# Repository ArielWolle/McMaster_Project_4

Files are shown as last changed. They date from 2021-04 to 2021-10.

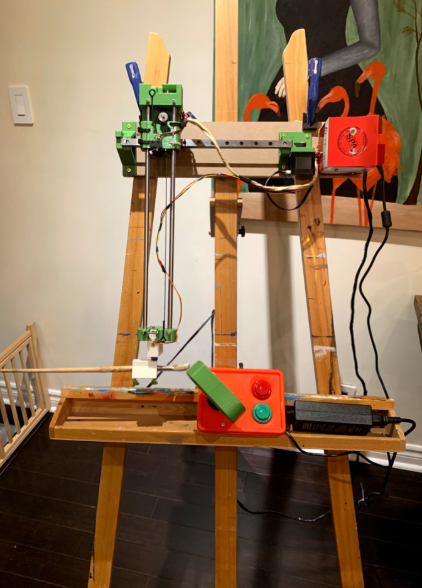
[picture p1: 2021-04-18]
Images/Plotter_on_easel.png

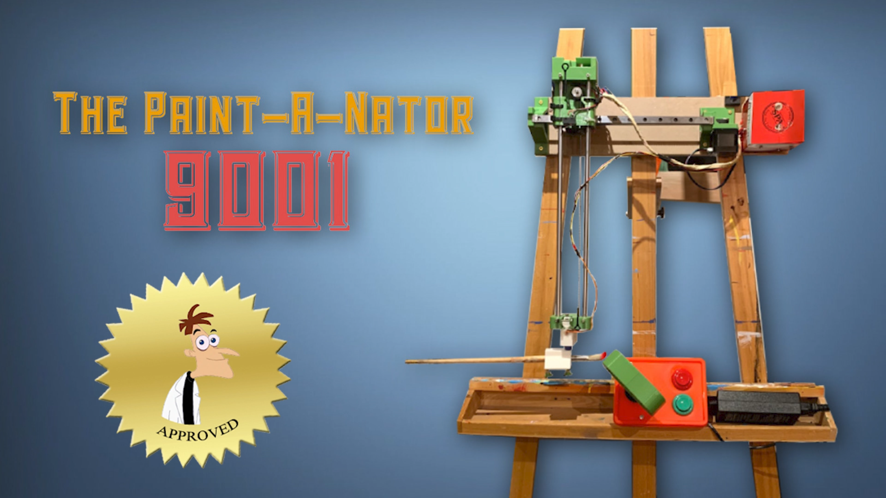
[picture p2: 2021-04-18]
Images/Plotter_title_page.png

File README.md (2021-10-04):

# McMaster_Project_4
ENG1P13 Project 4

This is a custom pen plotter based of of DIY-Machines design on thingiverse. This design was a end of year engineering project that I completed in a group of 4 where the challenge was to help a person with disiblities in their life. We chose to help the person be able to paint again. This design uses a custsom ergonomic joystick and 2 arcade style butons as inputs. 

https://www.youtube.com/watch?v=c9EO0ap5n0Y

Plotter_on_easel

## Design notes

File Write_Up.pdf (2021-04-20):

## Project Four – Power in Community

## The Paint-A-Nator 9001

ENGINEER 1P13 – Integrated Cornerstone Design Projects

Tutorial 03 & 15

Mon-46

Milica Nenadovic (nenadovm)

W. Tisuka Perera (pererw2)

Ariel Wolle (wollea)

Yara Sharafeldin (sharafey)

Submitted: April 14th, 2021.

1P13 DP-4 Final Report | Tutorial 03 & 15 | Mon-46

Table of Contents

Academic Integrity Statement

The student is responsible for performing the required work in an honest manner, without plagiarism and cheating. Submitting this

work with my name and student number is a statement and understanding that this work is my own and adheres to the Academic

Integrity Policy of McMaster University.

Milica Nenadovic | 400312492

X

The student is responsible for performing the required work in an honest manner, without plagiarism and cheating. Submitting this

work with my name and student number is a statement and understanding that this work is my own and adheres to the Academic

Integrity Policy of McMaster University.

W. Tisuka Perera | 400318373

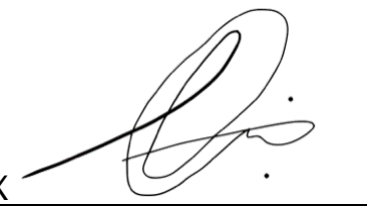
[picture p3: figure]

X

The student is responsible for performing the required work in an honest manner, without plagiarism and cheating. Submitting this

work with my name and student number is a statement and understanding that this work is my own and adheres to the Academic

Integrity Policy of McMaster University.

Yara Sharafeldin | 400294445

X Yara Sharafeldin

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

Integrity Policy of McMaster University.

Ariel Wolle | 400307171

X

Executive Summary

As a team we were tasked with analyzing and designing a product that would prove helpful to our client

and help ease her life through reducing pain and simplifying actions. We created a design that can be used for

painting large simple designs. The basis of this design is to convert a joystick movement to movement within a

pen plotter attached to the canvas. The classic joystick was then altered to fit to the client’s unique circumstance

by creating a handle where the client can put their hand in, lacking the necessity to close their fist and fingers

around the handle. Support was added to the design in order to add comfort and decrease fatigue in the client’s

wrist and forearm. Clamps were added to the pen plotter to increase applicability of the pen plotter to a variety

of canvas sizes (Figure 23, Section 2 of Appendix A).

Had we been given more resources, time, and money we would have made improvements to our design,

for example better motor drivers and longer linear rails/rods for the pen plotter. We would also print a real

electronic box or building one from wood (or possibly even a PCB as it provides better cooling and a better

opportunity for cable management). Finally, we would us an internal power source as a lighter option could be

used provided more resources, time, and money. If we were to go commercial, we would likely provide

different options on joystick sizes and linear rails/rod lengths.

Introduction

Background Information

The client is an artist who has been diagnosed with multiple different autoimmune diseases, including

chronic lymphedema, which causes swelling under the skin [1] (Figure 2, Section 1 of Appendix A),

particularly affecting the client’s arms and shoulders. They also have been diagnosed with fibromyalgia, which

is a widespread musculoskeletal pain [2] (Figure 3, Section 1 of Appendix A). Another condition the client has

been diagnosed with is ankylosing spondylitis, which triggers inflammation in their spine and joints, causing

stiffness [3] (Figure 4, Section 1 of Appendix A). These conditions together not only cause pain over their body,

but it also has several other side effects, from headaches, fatigue, loss of energy, and to difficulties with

concentration. The client has chronic pains that are unpredictable and sporadically changes in levels of pain

every day of the week. They have tried forms of art therapy and have practiced and used herbal medicines

however, and although they help, these methods of treatment are not permanent solutions. As an artist, more

specifically a painter, having these conditions makes painting a difficult task. The client has difficulties painting

more finer details as their pains tend to increase, and holding paintbrushes is hard as they occasionally

experience difficulties with their fine motor skills (Figure 1, Section 1 of Appendix A).

Refined Problem Statement

Increase the client's ability to complete non detailed strokes while painting or using touchscreens

effortlessly through joysticks and large buttons/sliders.

Objectives and Constraints

Our main objectives were easy to prototype, minimizes fatigue on Client, and reliability of product. The

constraints relative to our design solution were a weight under 5 pounds (10 if client is sleeved), and 3 ½ inches

width of the client’s hand.

Existing Ideas and Solutions

Pen plotters have been a thing since around the 1980’s but the Paint-A-Nator 9001 allows its users to

paint with limited physical abilities. The rest of these plotters were not usually used for painting and when they

were, the controls did not apply for people with disabilities, so we took it upon ourselves and modified one to fit

our needs. When searching online for 3D printed pen plotter you will find tons on Thingiverse, however, due to

our tight time schedule we used an open-source pen plotter[4].

Conceptual Design

Ideation

We brainstormed multiple different approaches on possible solution options and through discussion as a

team leaned towards a design with an effortless input and an output, pen plotter, which would do the painting.

Once we had our refined problem statement, we concluded a modified pen plotter would be the best solution for

our design. Our initial design from all 4 members included pen plotter but the main differences where the

control interface, we had multiple ideas from joysticks vs slider to shoulder support vs wrist support. After

deliberation and support from science students we decided on a wrist supporting joystick and 2 button

controllers.

Design Alternatives and Decision Matrix

As you can see in Figure 13 in Section 2, we had alternative designs in joystick or possibly even using a

touch screen tablet (Figure 14, Section 2). In the end we decided that a stereotypical joystick design would be

supreme with a couple alterations to increase the ergonomics of the design to decrease pain and discomfort in

the client. A large alteration included a change in handle as a stereotypical handle would require the client to grip a bulb whereas our design allows them to insert their hand as it does not require them to close their fist,

better fitting it to the client.

Design Evaluation

Some comments made during our first design review meeting were to consider when the client wants to

change paint colours, how easy the design is to fix when faced with malfunctions, are there any time delays or

such in processing time, and variation of intended texture of paint. Motors and buttons were added to turn the

paintbrush to account for the texture variation and to allow for easy access to change colour or add more paint,

the design also allows for paintbrush change. Certain materials were used to minimize time delay. The design

prototype was made with simple components to add simplification for any needed correction due to

malfunctions.

During the second design review meeting the large concept that was questioned was whether this design

would cause a disconnect between the client and painting. We asked the client what is important to them when

painting, they answered that they did not particularly enjoy painting backgrounds or repainting canvases. This is

what our design is intended for, therefore we did not make alterations due to this. Although a comment from the

client was that closing their fists result in pain and fatigue, and that wrist and forearm support is preferred. Due

to this we altered the handle design, our design already allows for movement of the joystick allowing the client

to easily use the design with support of the wrist and/or forearm (Figure 17. Section 2 of Appendix A).

Final Proposed Design

Our final design is a 4 axis CNC painting machine, controlled by a custom control board with an ergonomic

joystick and 2 arcade buttons.

The Basics of the Design:

This design works using 2 stepper motors with belts for the x and y axes, the z and rotation axes are each

controlled by servo motors. The x axis uses a linear rail to constrain the movement while the y axis uses 2 pairs

of linear rods and bearings. The z axis is constrained by a linear bearing and rod. The rotational axis is

constrained since it is attached directly onto the SG-9 servo, which in turn is glued down the end of the y axis.

Each 4 directions of the x and y axis have a limit switch which stops movement if actuated. To control all these

axes there is a control box connected to the machine with a 2.5-meter-long cable which includes an 8-axis

joystick and 2 arcade buttons. The main body and controller were modelled in Autodesk Inventor in two

different assemblies (Figure 21 & 22. Section 2 of Appendix A).

The Electronics:

All these Inputs and Outputs are wired up to the Raspberry Pi Foundation’s new Raspberry Pi Pico

microcontroller based off the RP2040 microcontroller according to the wiring diagram shown below. (Figure

18. Section 2 of Appendix A)

The motors are driven off 12 volts using the L298D motor driver using 4 PWM signals from the Pico each

(These signals are PWM and not digital as they are micro stepped). The servos are driven from the Pico using

the on chip PWM generator with a minimum pulse of 500ms and maximum pulse of 2250ms. The Pico only

accepts 3.0-5.5v so we included a 12v to 5v buck convertor to power it. Lastly the power supply is rated for 12v

6 amp but using a multimeter we concluded it draws a max of just under 4 amps leading to a max power draw

of around 48 Watts.

The Code:

The RP2040 Firmware is coded in Circuitpython, an Adafruit industries fork of python focused on

microcontrollers. The external libraries used are the adafruit_motor library used for controlling the 4 included

motors (2 stepper and 2 servos). The motors, limit switches, joystick, and arcade buttons are first initialized.

Then a variable called “angle” is initialized to keep track of the servo motor’s current angle. The rotation servo

is then reset to parallel with the painting surface before the main loop is ran. For the main loop we check if each

input is “True” and the according limit is not reached if so, turn the respective motor. Pseudocode for this

program is included in an image below (Figure 19. Section 2 of Appendix A)

Using the Device

Our device is used by attaching it your easel on top of your canvas using clamps. You then insert and screw in

your paintbrush. Then flick the power switch to turn on the device. As the servo defaults to parallel with the

painting surface you easily add paint onto your paintbrush. Using the controller, you then turn the servo onto the

painting then after, put your hand within the joystick and paint to your hearts content.

Final Drawings

The final engineering drawings have a more detailed description of the assemblies of the controller and device

(Figure 24, 25. Section 3 of Appendix A).

These drawing are slightly different than the real physical product due to time constraints. The clamps we used

for our physical product was a set of household clamps unlike the 3D printed ones on the assembly. Lastly the

body of the controller was different due to budget and time constraints as we have time to print a custom box or

money to buy one.

Objectives/Constraints Met

Objectives: Easy to prototype, Minimizes Fatigue on Client, and Reliability of Product

We believe we met almost all our objectives to a high degree of consistency, our product took us less

than three weeks to physically prototype, our product allows the client to put energy into our product instead of

painting and works reliably throughout the day most of the time. The metrics we used for easy to prototype are

total prototyping time which as stated was 3 weeks, which we understood as completing the objective. The

metric we used for minimizes fatigue on client is effort it takes to completely cover one whole canvas in one

colour, after testing it on Ariel and 3 of his family members they stated an average of 80% less energy which we

understood as completing the objective. For reliability of the product Ariel tested the product for about 6 hours

with a three thirty-minute breaks in between and it never failed, which we understood as completing the

objective. The limitations of our metrics where a small sample size for fatigue that did not even include our

target client, and we only had one person test it for 6 hours all in one day. These limitations mean our metrics

are pretty accurate but could be improved with mainly a larger sample size.

Constraints: Weight Under 5 pounds (10 if client is sleeved), 3 ½ inches width of the client’s hand

We also believe we met all the design constraints as although there were a variety of constraints

provided, these were the only two relevant to our solution. As the Joystick and Pen-Plotter each are each within

the weight constraint of the client to provide the independence the client asked for. The joystick obliges by the

constraint of the client’s hand for them to be capable of inserting their hand for usage without pain.

Bill of Materials

Name | Specification | Price | Link
3D Printing Filament | 1.75mm 1KG | $19.95 | Filaments.ca (https://filaments.ca/collections/3d-filaments/products/econofil-1kg-pla-filament-green-1-75mm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)
Power Supply | 12V 6A | $23.99 | Amazon.ca (https://www.amazon.ca/gp/product/B086JNYDX7/ref=ppx_yo_dt_b_asin_title_o03_s00?ie=UTF8&psc=1))
Linear Rod | 8mm diameter, 400mm long | $20.53 | Amazon.ca (https://www.amazon.ca/gp/product/B01KLE9KKU/ref=ppx_yo_dt_b_asin_title_o04_s00?ie=UTF8&psc=1))

Linear Rod | 8mm diameter, 500mm long | $30.89 | Amazon.ca (https://www.amazon.ca/gp/product/B07W6V35YZ/ref=ppx_yo_dt_b_asin_title_o05_s00?ie=UTF8&psc=1)
Motor Driver | 2 Pack L298N | $13.99 | Amazon.ca (https://www.amazon.ca/gp/product/B08DSFLQ3K/ref=ppx_yo_dt_b_asin_title_o05_s01?ie=UTF8&psc=1)
2x SIMAX3D Stepper Motors | NEMA 17 | $37.98 | Amazon.ca (https://www.amazon.ca/gp/product/B0857489JD/ref=ppx_yo_dt_b_asin_title_o05_s01?ie=UTF8&psc=1)
GT2 Smooth Timing Pulley | 3mm Bore | $11.99 | Amazon.ca (https://www.amazon.ca/gp/product/B086KZS9LH/ref=ppx_yo_dt_b_asin_title_o05_s03?ie=UTF8&psc=1)
Linear Rail | 300mm | $32.29 | Amazon.ca (https://www.amazon.ca/gp/product/B078M7H6GB/ref=ppx_yo_dt_b_asin_title_o05_s03?ie=UTF8&psc=1)
Microswitch | 10 Pcs | $11.99 | Amazon.ca (https://www.amazon.ca/gp/product/B08736NP44/ref=ppx_yo_dt_b_asin_title_o05_s03?ie=UTF8&psc=1)
SG90 Servos | 5 Pcs | $19.99 | Amazon.ca (https://www.amazon.ca/gp/product/B07KR24YX8/ref=ppx_yo_dt_b_asin_title_o05_s03?ie=UTF8&psc=1)
GT2 Set | Timing Belt, 4 Teeth Pulleys | $15.99 | Amazon.ca (https://www.amazon.ca/gp/product/B07PQRJL2W/ref=ppx_od_dt_b_asin_title_s03?ie=UTF8&psc=1)
Linear Bearings | 25mm Long | $20.29 | Amazon.ca (https://www.amazon.ca/gp/product/B07CRLSS7N/ref=ppx_od_dt_b_asin_title_s03?ie=UTF8&psc=1)
Linear Bearings | 45mm Long | $16.99 | Amazon.ca (https://www.amazon.ca/gp/product/B083XQTH41/ref=ppx_od_dt_b_asin_title_s03?ie=UTF8&psc=1)
Lock Nut | Assorted (M3-M12) | $15.99 | Amazon.ca (https://www.amazon.ca/gp/product/B07GNXDQJZ/ref=ppx_yo_dt_b_asin_title_o00_s00?ie=UTF8&psc=1)
Fastener Kit | Assorted (M2-M5) | $34.89 | Amazon.ca (https://www.amazon.ca/gp/product/B07GXMRYXR/ref=ppx_yo_dt_b_asin_title_o05_s00?ie=UTF8&psc=1)
Scrap MDF | 5/8” Thick | $5.00 | On Hand
Total Price | | $332.65

Constructing the Product

We completed a physical design of our product as can be seen in Figure 23, in Section 2 of Appendix A. For the

pen plotter we used an open source (CC attribution 4.0 International (CC BY 4.0)) design for the x, y and z axes

with permission and excitement [4]. This design was meant for drawing parallel to the ground, so we needed to

modify to work on an easel. The modified sections of the pen plotter include the pen slider, addition of the

rotation axis, and modified z axis. We also constructed a controller and electronics box. The construction took

about 2.5 weeks including the about 3 days spent 3D printing. We used 3D printing for the main parts as it was

very cheap and accessible as a group member already owned a 3D Printer. If we had the resources, we might

have CNC milled the parts in 6061 aluminium due to the increased rigidity without a massive weight increase.

For linear rails vs rods, we used rails for the x axis as it was cheaper to buy one 300mm rail than 2 300 mm

linear rods, on the y axis we attempted to implement linear rails but the rods where much simpler. The

electronics box was built from a waste cardboard box due to budget and time restriction, building a wooden box or 3D printing one would have been the right choice, but we ran out of both money and resources. For the

microcontroller, the Raspberry Pi Pico only costs $4 compared to the original design’s $20-$40 Arduino Uno.

Additionally, we removed the z axis from our machine as it did not benefit us and the rotational axis provided

us with virtual z axis functionality. Lastly the joystick handle was 3D printed but with more time and resources

we would have but a layer of cloth onto to easy the client in her everyday use.

Conclusion

Looking Ahead

While we believe our design is great, we also believe there are many areas for improvement that would just be a

result of greater funding. In terms of time, we could have designed and printed or built from wood a real

electronics box or even a PCB for better cooling and cable management. Currently the power supply is external

which does reduce weight but could create a bad situation if it fell. In the money department we would have

spent it on motor drivers and longer linear rails/rods. The motors produce a whine due to the L298N stepper

drivers we used, they are not silent micro stepping drivers and could be easily replaced if we put in a greater

investment into the project. Currently the max painting surface is around 300mm x 400mm, but this is just

constrained due to the limited money we could spend on smaller linear rails/rods. Other than those small

improvements we believe our prototype is still fully functional and completes its job well.

Looking Back

Looking back upon the project we believe that our group did a great job. The fact that we completed a physical

working prototype that looks almost identical to many of our concept sketches is a representation of our design

process. This project was a great opportunity to display all the skills we have learned throughout this school

year and showcase our abilities. Through this project we have learned the importance of collaboration as every

team member has different qualities, experiences, and mindsets they can add to optimize our design. Our design

process worked well as we split up the work evenly and allowed each team member to excel in their own

separate sections. Ariel had prior maker experience, so he took on the task of making the design, Tisuka had

prior video editing and CAD experience so he took on the task of editing our video and completing the joystick

handle CAD, Milica had prior experience with CAD and writing so she helped lead the milestones and

contributed to the CAD, Yara had prior experience with CAD and writing so gave input in the process and

contributed to the pre-recorded video. Overall, we believe our group did an excellent job on this project and

hope to make something even cooler in the future courses.

Project Contribution

Name, MacID | Contributions
Ariel Wolle, wollea | Coded Firmware for Microcontroller Designed parts of Final CAD Physically built Projects Completed multiple parts of final report Wrote part of script for video Lead presentations
Milica Nenadovic, nenadovm | Strongly Participant in completing Milestones Participating in completion of final report and Organization Wrote part of script for video
W. Tisuka Perera, pererw2 | Designed Joystick Device Model in Autodesk Inventor (initial, refined) Completed multiple parts of the final report Wrote part of script for the video Created and edited Pitch Video for Final Presentation
Yara Sharafeldin | Checked the reference’s credibility Participated in video

List of Sources (IEEE Format)

1. H. Brorson, A. Warren, L. J. Borud, S. A. Slavin, “Lymphedema: A Comprehensive Review,” Annals of plastic surgery, Oct-2007. [Online]. Available: https://pubmed.ncbi.nlm.nih.gov/17901744/. [Accessed: 12-Apr-2021].
2. D. J. Clauw, “Fibromyalgia: an overview,” The American journal of medicine, 2009. [Online]. Available: https://pubmed.ncbi.nlm.nih.gov/19962494/. [Accessed: 12-Apr-2021].
3. E.B. Gouveia, D. Elmann, M.S. Morales, “Ankylosing spondylitis and uveitis: overview,” Rev Bras Reumatol, Oct-2012. [Online]. Available: https://pubmed.ncbi.nlm.nih.gov/23090374/. [Accessed: 12-Apr-2021].
4. D. I. Y. Machines, “Easy 3D Printable CNC Drawing Machine.” [Online]. Available: https://www.thingiverse.com/thing:4537916. [Accessed: 14-Apr-2021].

Appendix A: Section 1-3

Section 1

Client Meeting Notes:

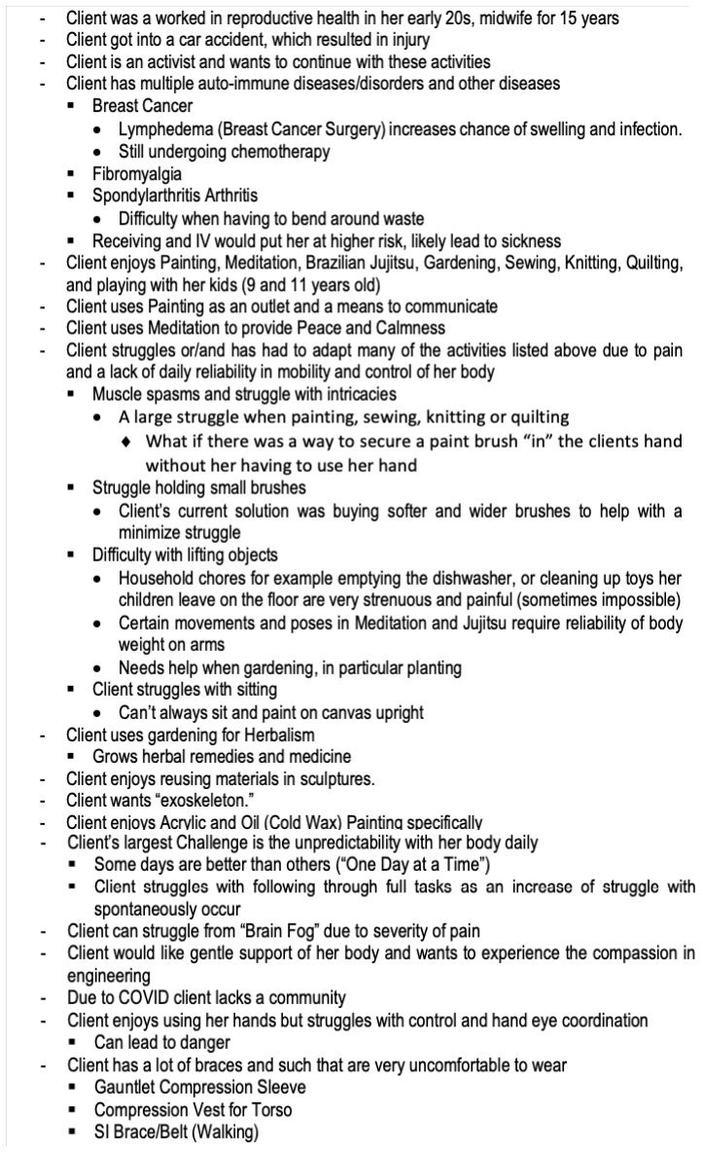
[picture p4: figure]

Figure 1. Milestone 1 - Client Meeting Notes

Medical Documents:

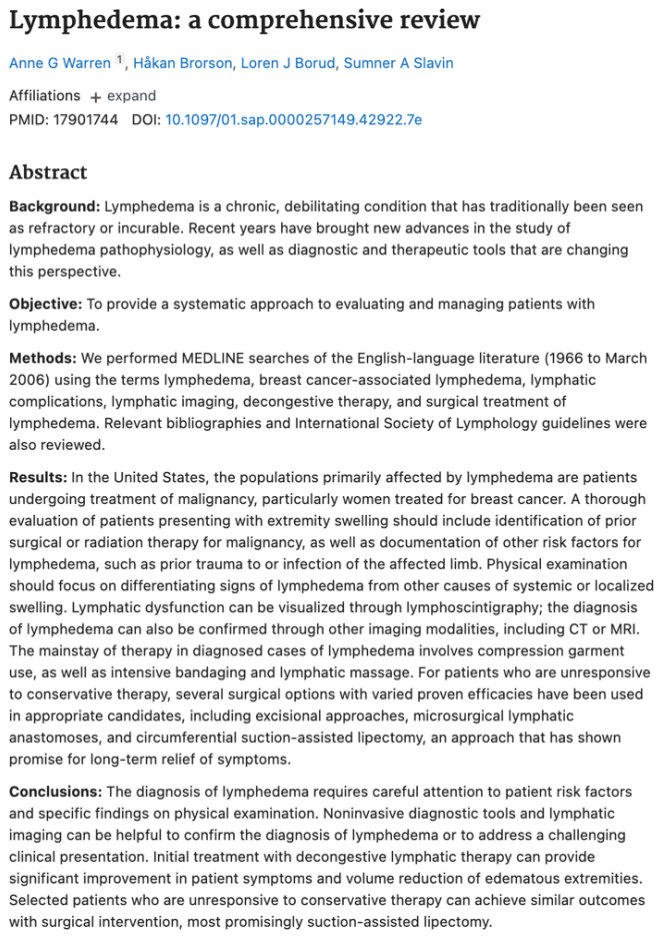
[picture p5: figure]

Figure 2. Lymphedema: a comprehensive review

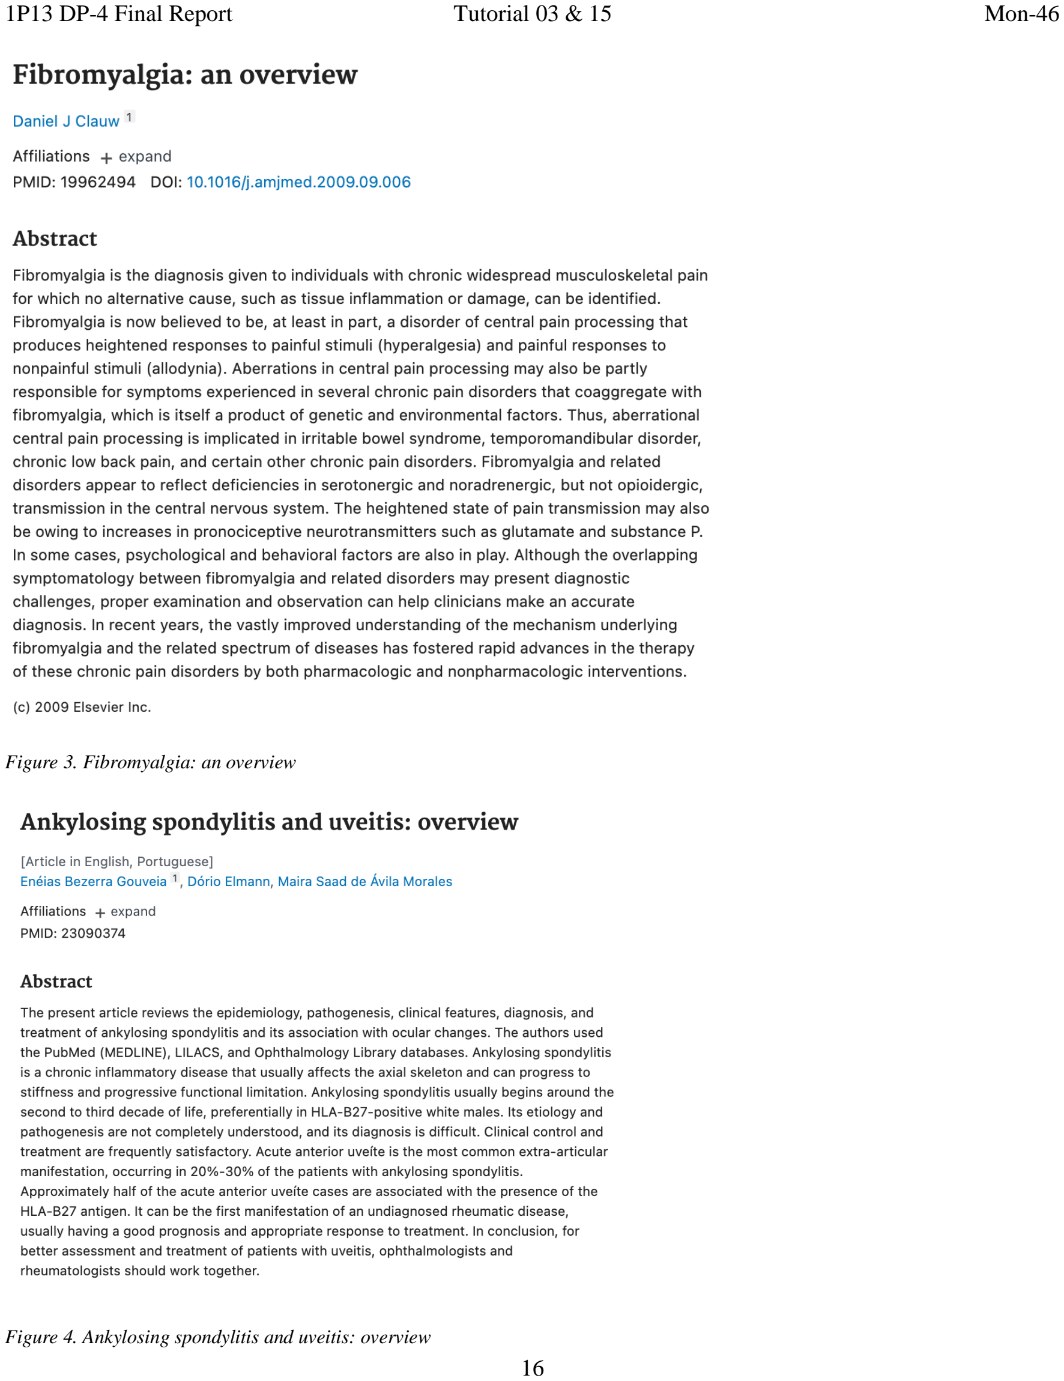
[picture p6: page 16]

Figure 3. Fibromyalgia: an overview

Figure 4. Ankylosing spondylitis and uveitis: overview

How/Why Ladder:

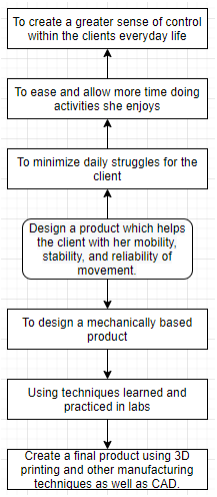
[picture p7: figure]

Figure 5. Milestone 1 - How/ Why Ladder

Commercial Products:

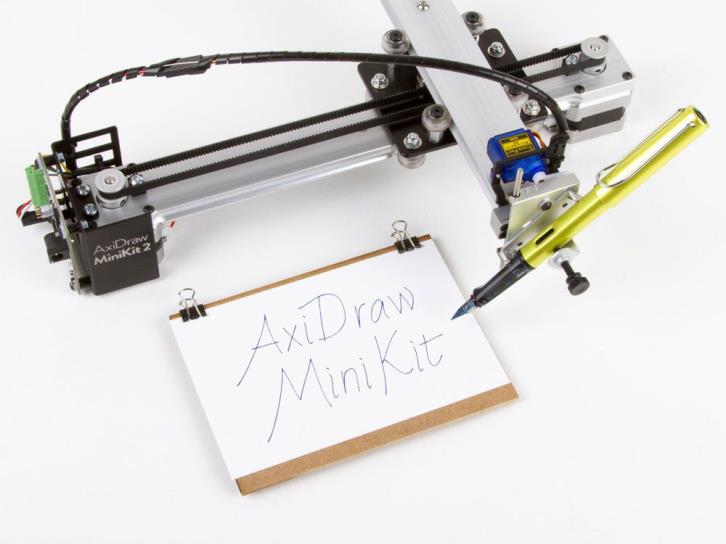
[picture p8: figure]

Figure 6. Commercial Product: AxiDraw MiniKit 2 – Compact Pen Plotter DIY-Kit

Section 2

Morph Chart:

Functions | Means
1 | 2 | 3 | 4
Accessible controls | Joystick | Large Buttons | Sliders | Motion Control
Accurate Positioning | Steppers | Servos | Homing Switches | …
Response Time | Direct connection | Wireless Connection | Faster Microcontroller | …
Applicable to multiple canvas/tablet sizes | Extensions | Multiple means of grip | … | …
Ease in mounting | Canvas Clamps | … | … | …

Table 1. Milestone 2 - Morphological Chart

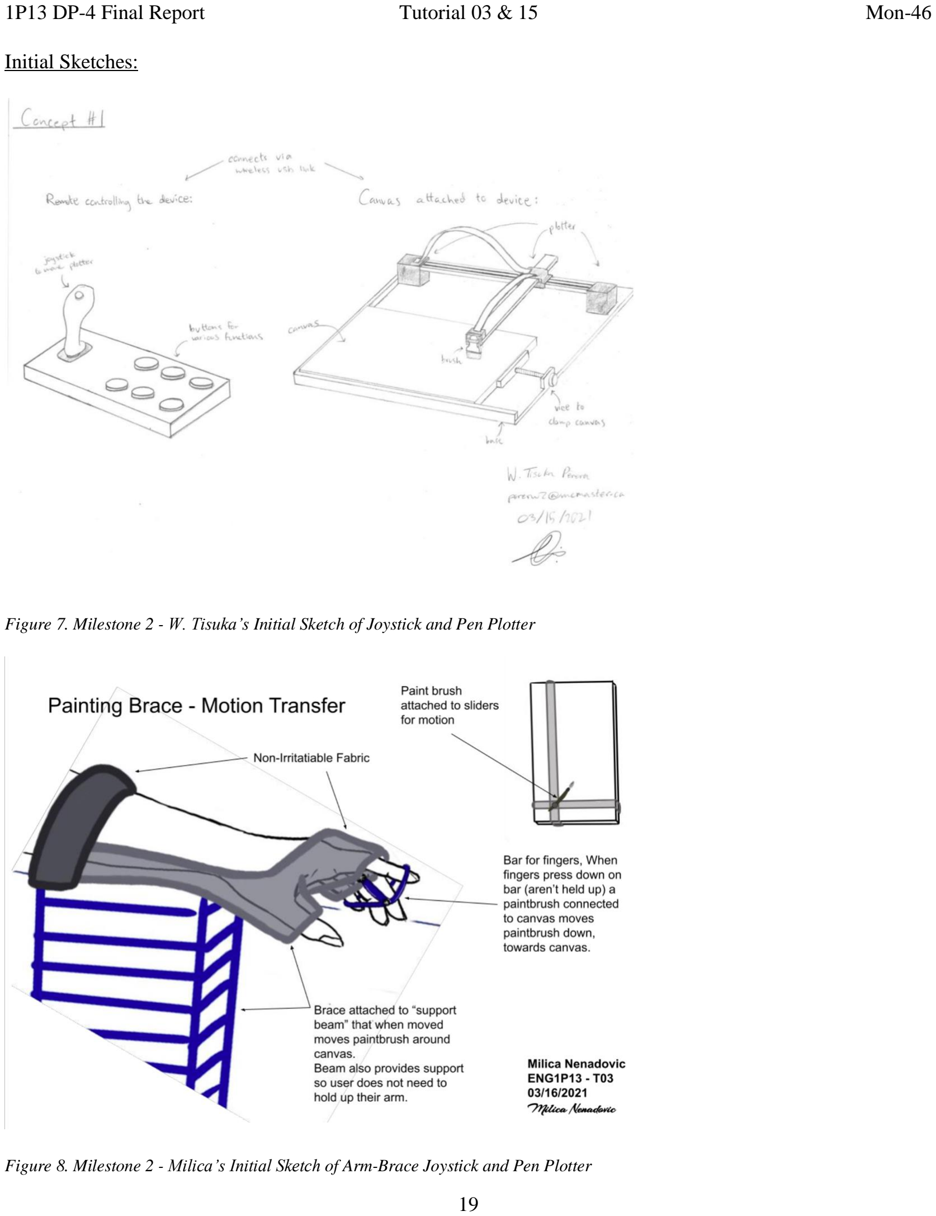
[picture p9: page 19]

Initial Sketches:

Figure 7. Milestone 2 - W. Tisuka’s Initial Sketch of Joystick and Pen Plotter

Figure 8. Milestone 2 - Milica’s Initial Sketch of Arm-Brace Joystick and Pen Plotter

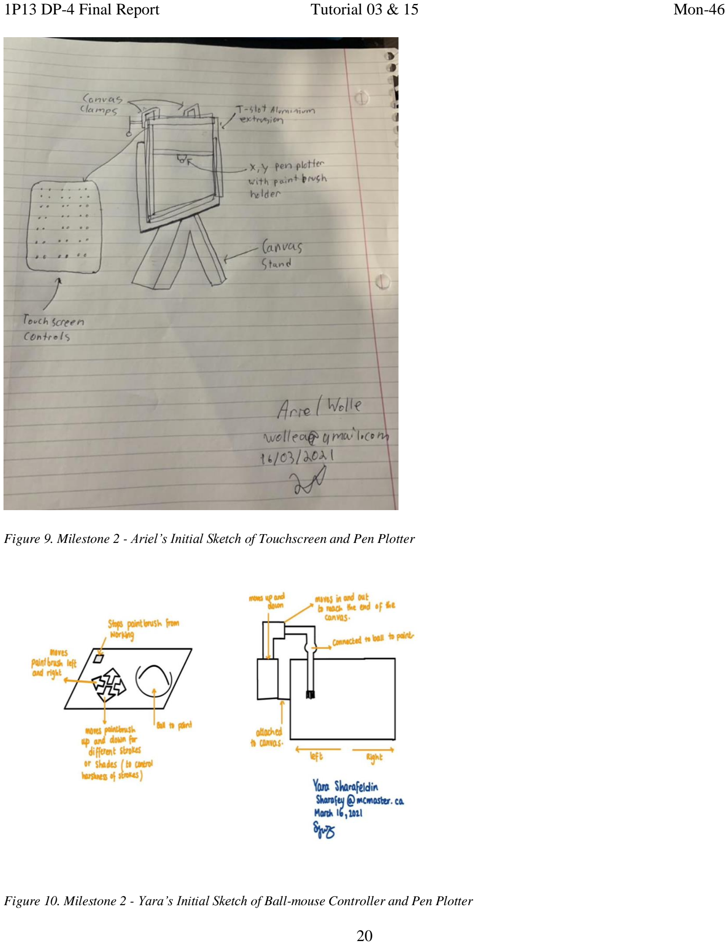
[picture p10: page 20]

Figure 9. Milestone 2 - Ariel’s Initial Sketch of Touchscreen and Pen Plotter

Figure 10. Milestone 2 - Yara’s Initial Sketch of Ball-mouse Controller and Pen Plotter

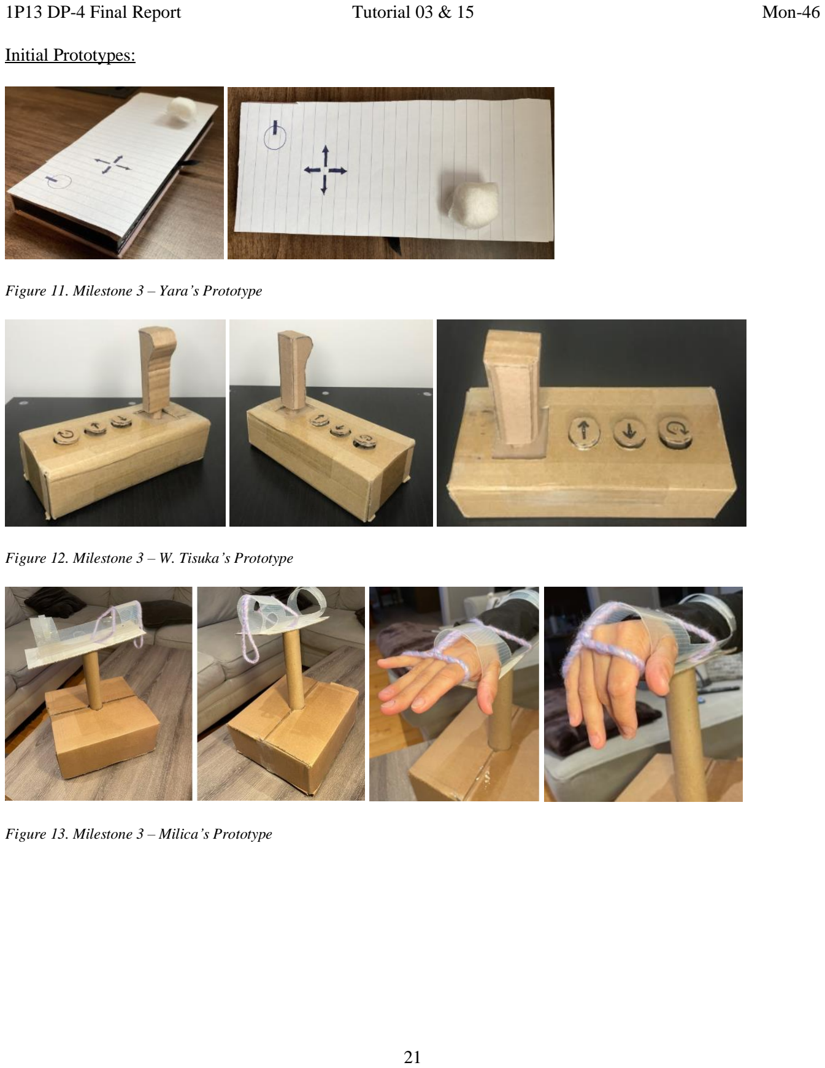
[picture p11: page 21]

Initial Prototypes:

Figure 11. Milestone 3 – Yara’s Prototype

Figure 12. Milestone 3 – W. Tisuka’s Prototype

Figure 13. Milestone 3 – Milica’s Prototype

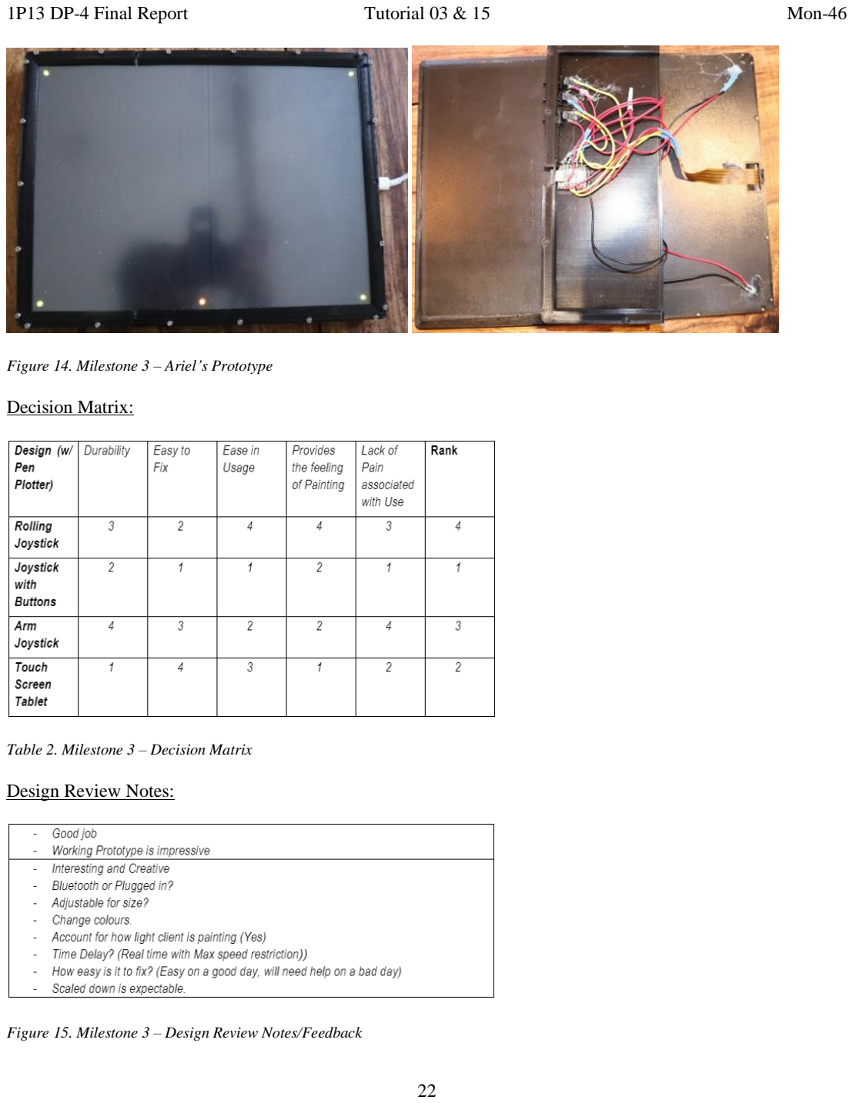
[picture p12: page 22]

Figure 14. Milestone 3 – Ariel’s Prototype

Decision Matrix:

Table 2. Milestone 3 – Decision Matrix

Design Review Notes:

Figure 15. Milestone 3 – Design Review Notes/Feedback

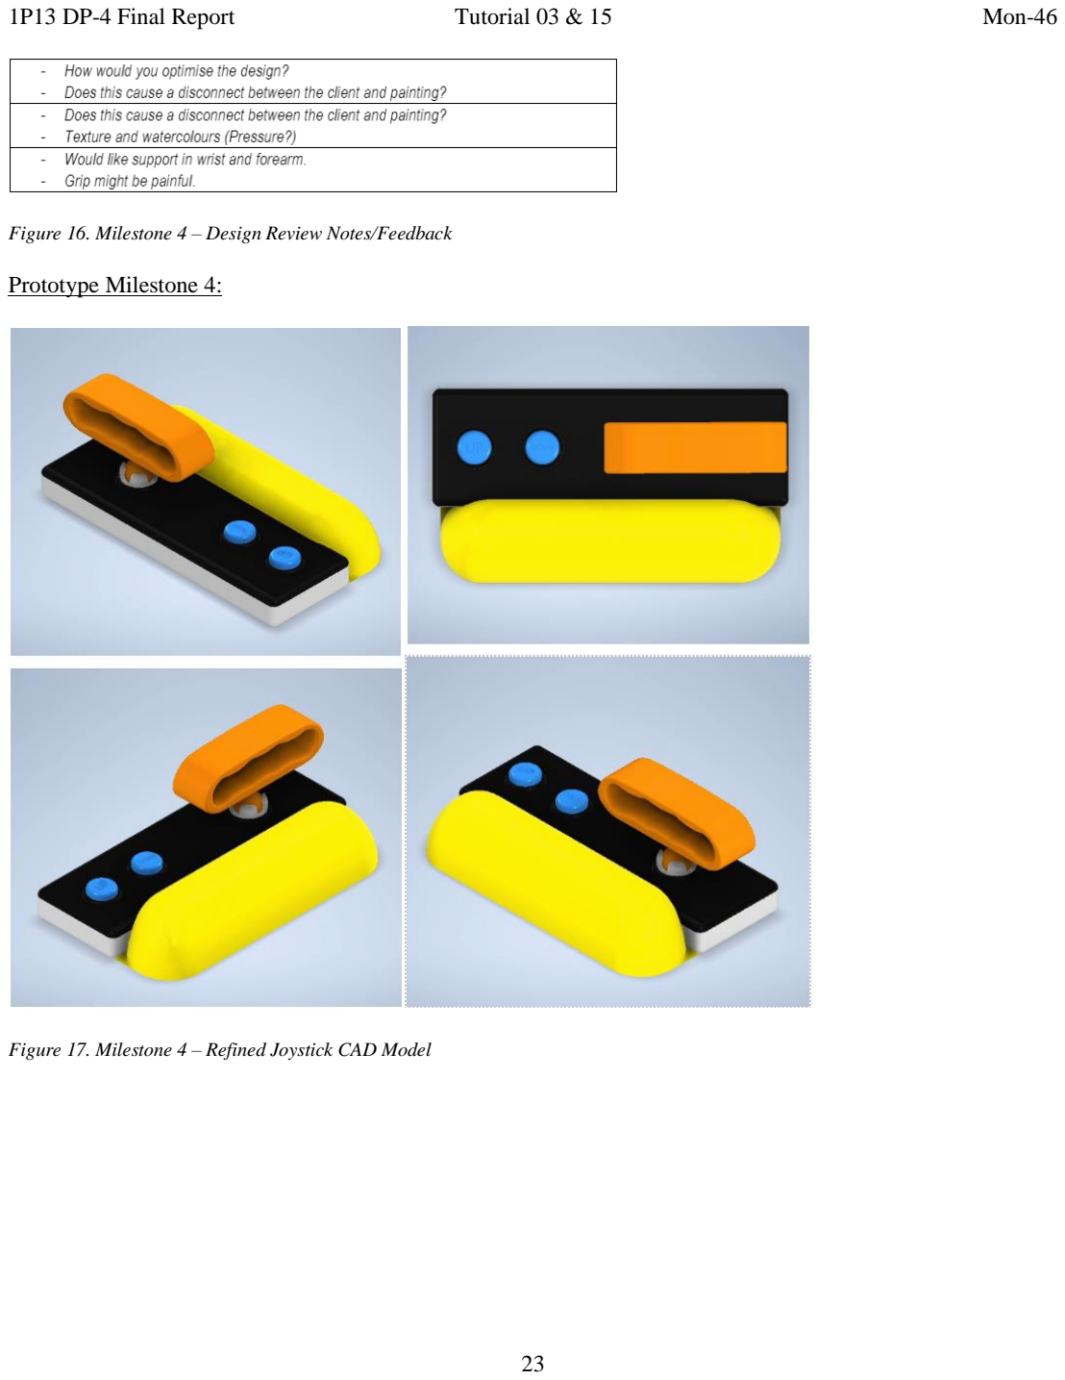
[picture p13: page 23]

Figure 16. Milestone 4 – Design Review Notes/Feedback

Prototype Milestone 4:

Figure 17. Milestone 4 – Refined Joystick CAD Model

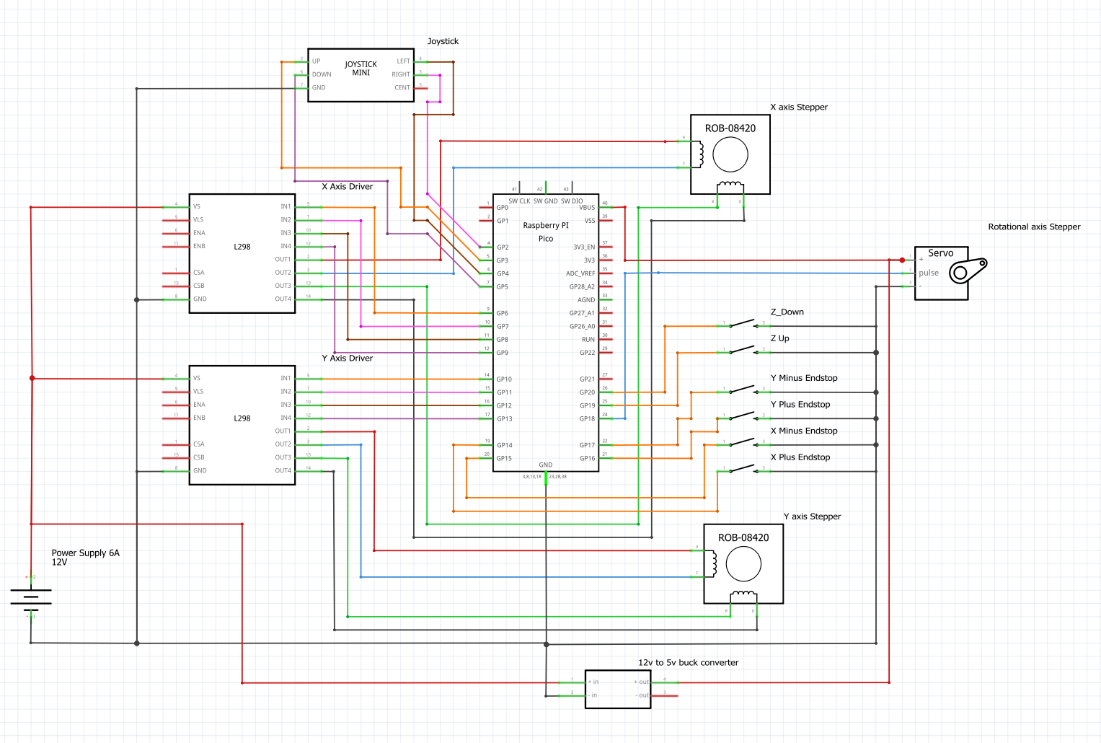
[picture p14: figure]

Figure 18. Wiring Diagram for Pen Plotter

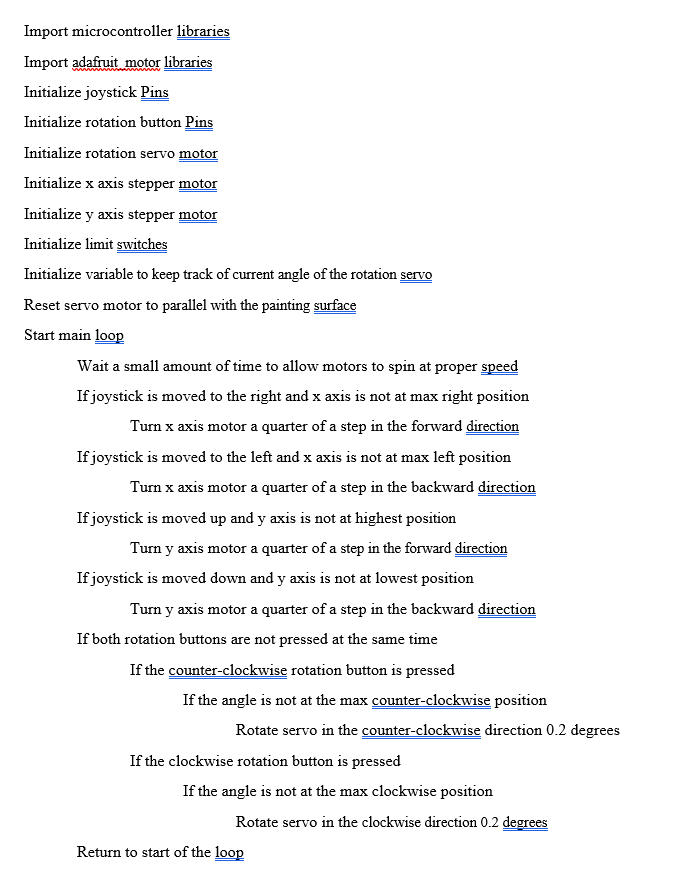
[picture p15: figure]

Figure 19. Pseudocode for Pen Plotter

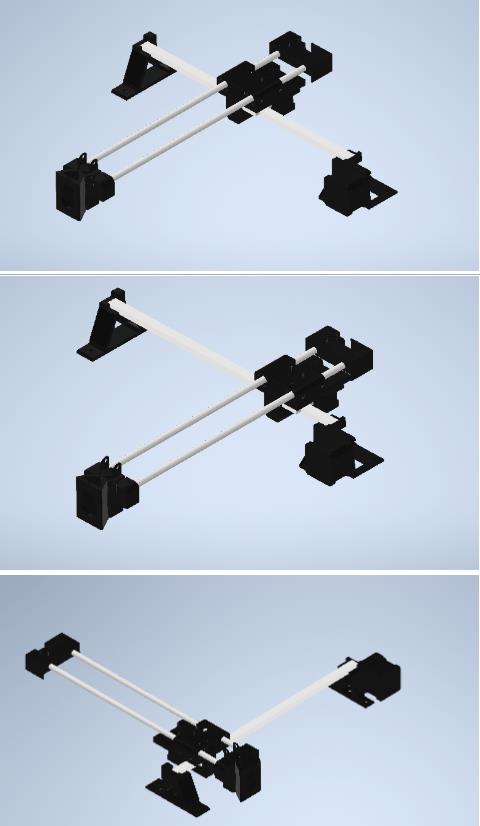
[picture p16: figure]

Figure 20. Milestone 4 – Pen Plotter CAD Model

Final Prototype:

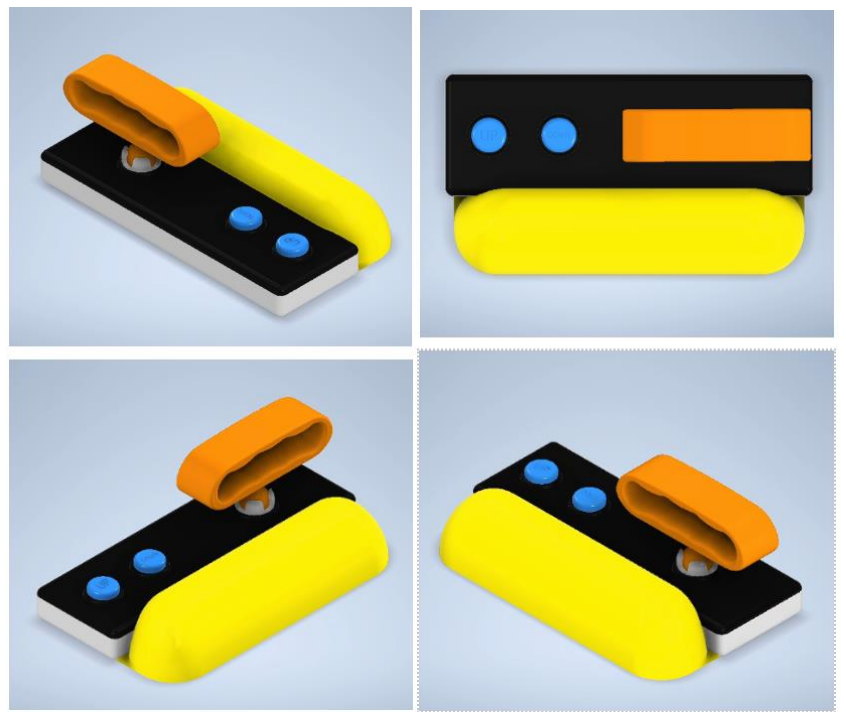
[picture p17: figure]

Figure 21. Milestone 4 – Refined Joystick CAD Model

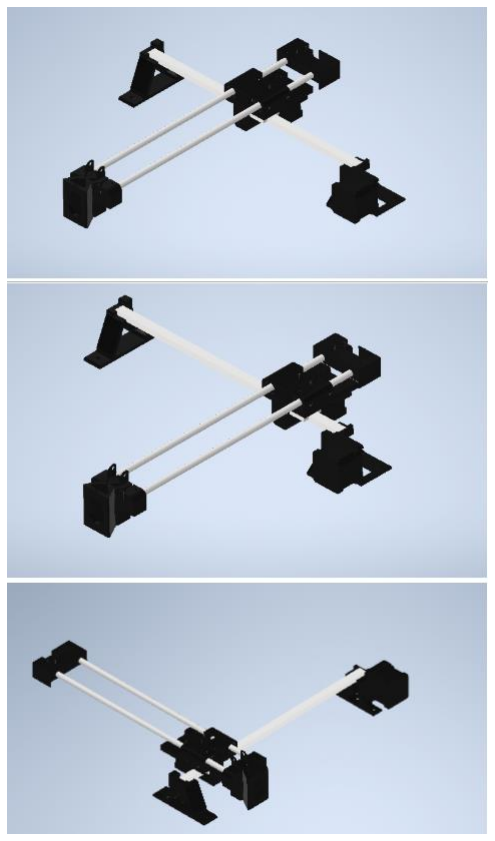
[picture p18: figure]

Figure 22. Milestone 4 – Pen Plotter Model Assembly

Physical Prototype for Testing:

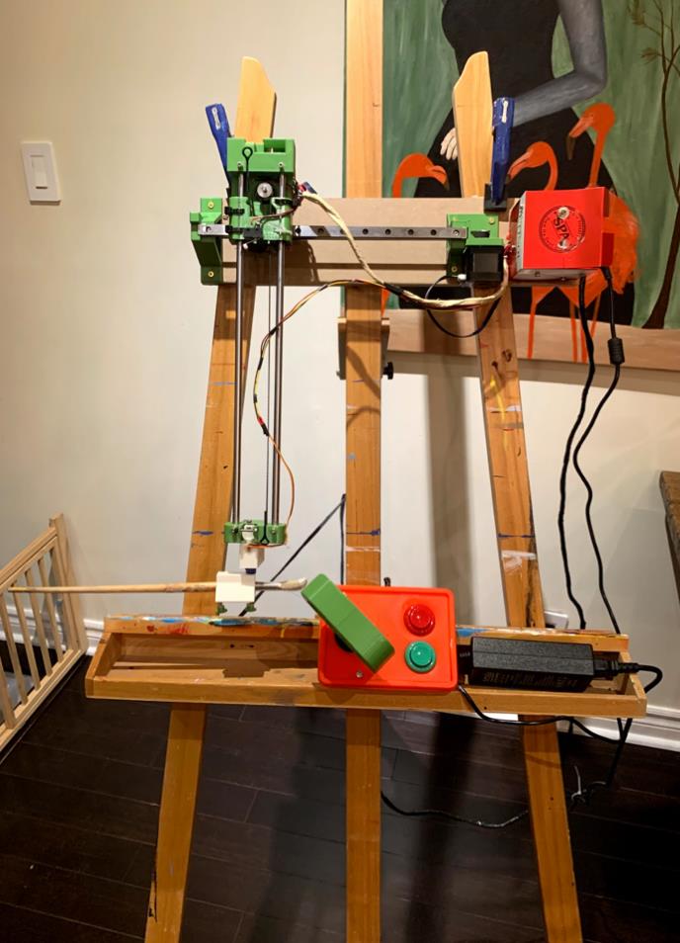
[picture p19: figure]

Figure 23. Paint-A-Nator 9001 (Pen Plotter clamped onto easel, Joystick device resting on easel)

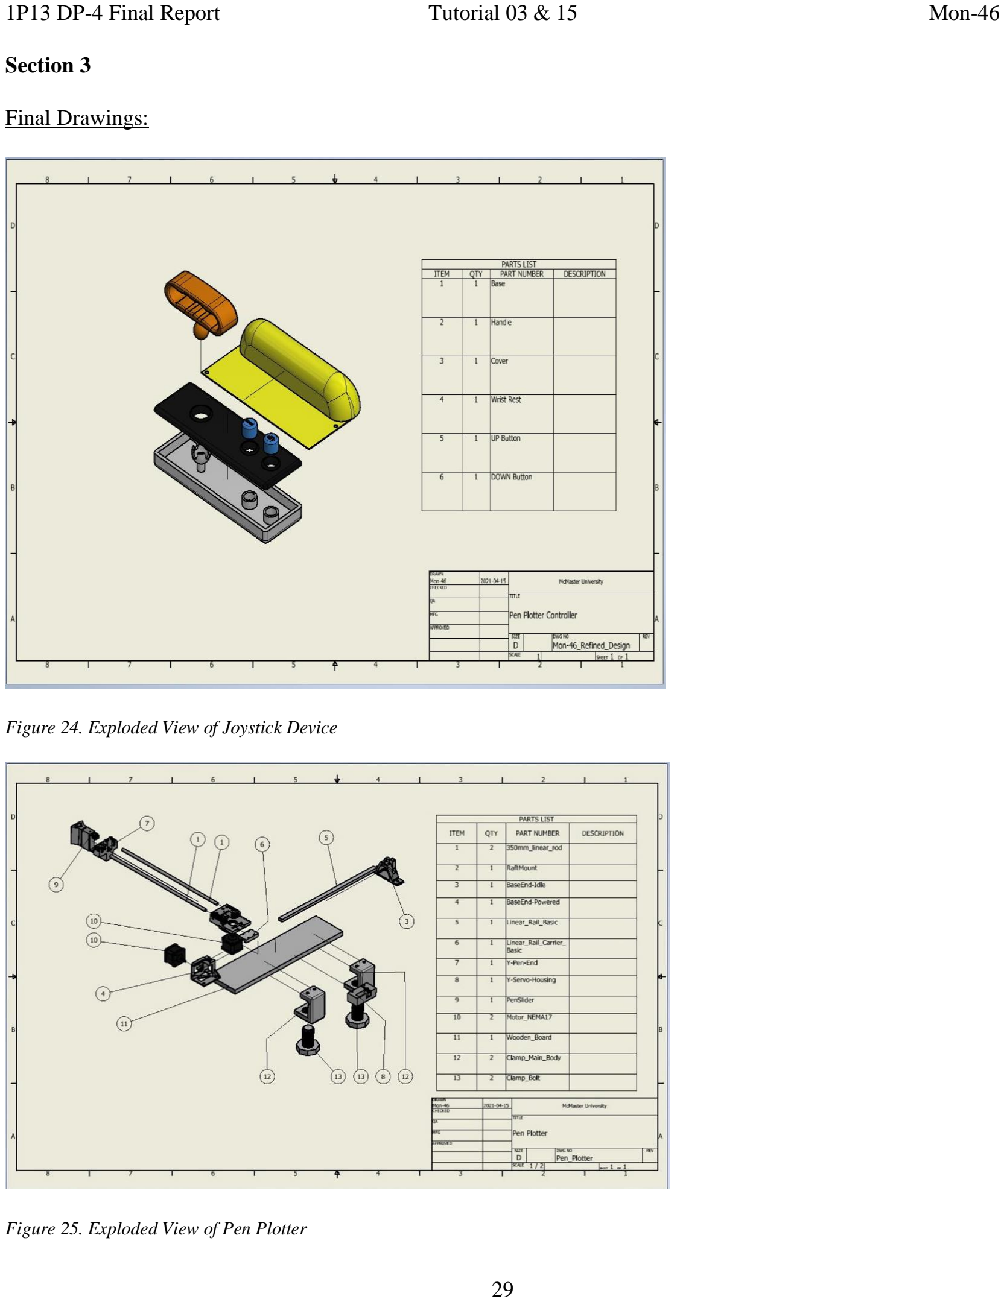
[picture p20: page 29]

Section 3

Final Drawings:

Figure 24. Exploded View of Joystick Device

Figure 25. Exploded View of Pen Plotter

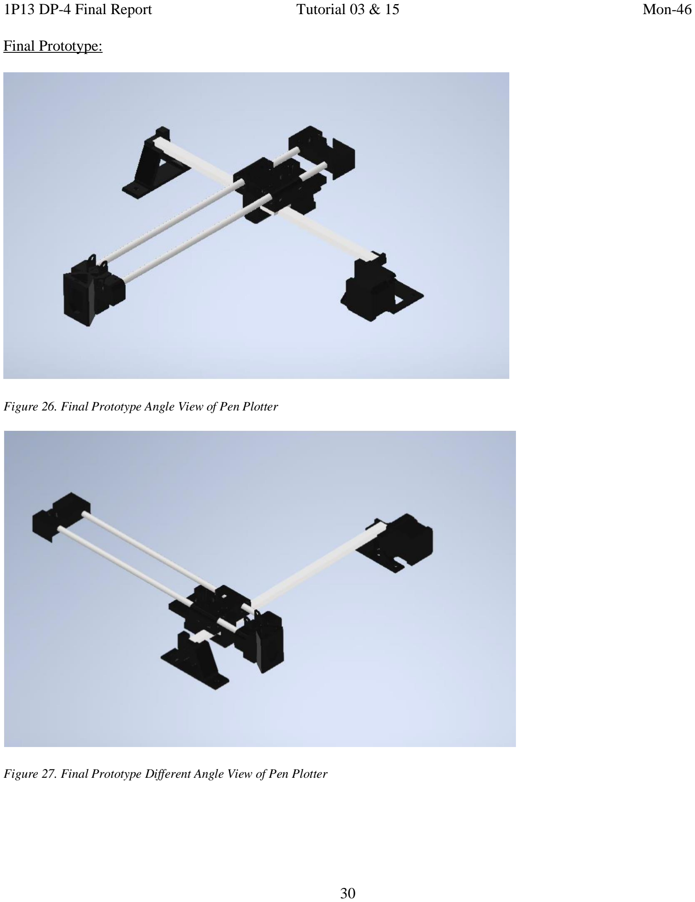
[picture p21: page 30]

Final Prototype:

Figure 26. Final Prototype Angle View of Pen Plotter

Figure 27. Final Prototype Different Angle View of Pen Plotter

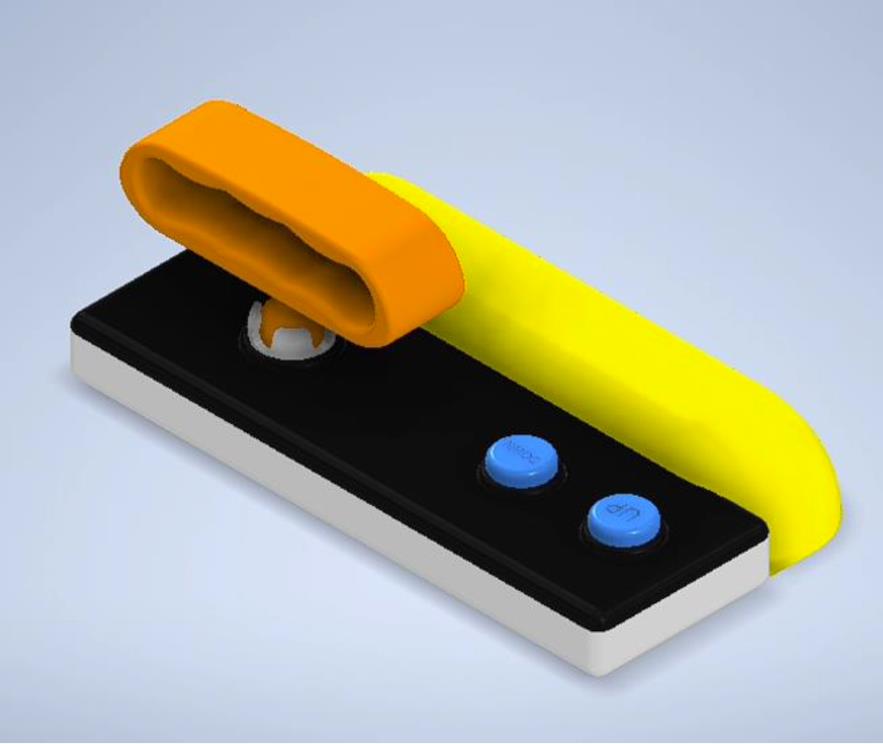
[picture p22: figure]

Figure 28. Final Prototype Angle View of Joystick Device

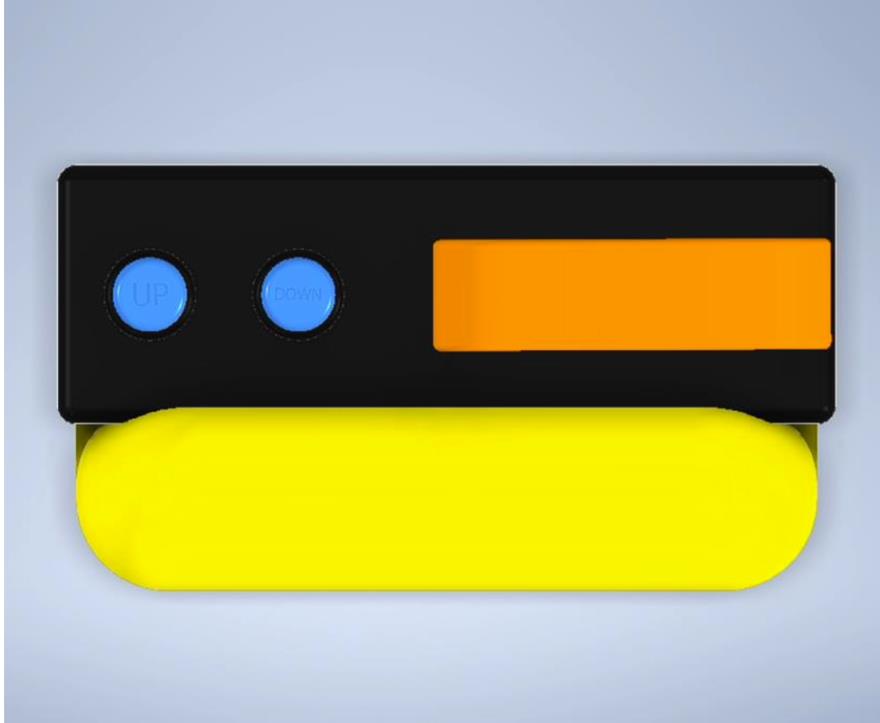
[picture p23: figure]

Figure 29. Final Prototype Top View of Joystick Device

Bill of Materials:

Name | Specification | Price | Link
3D Printing Filament | 1.75mm 1KG | $19.95 | Filaments.ca (https://filaments.ca/collections/3d-filaments/products/econofil-1kg-pla-filament-green-1-75mm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)
Power Supply | 12V 6A | $23.99 | Amazon.ca (https://www.amazon.ca/gp/product/B086JNYDX7/ref=ppx_yo_dt_b_asin_title_o03_s00?ie=UTF8&psc=1))
Linear Rod | 8mm diameter, 400mm long | $20.53 | Amazon.ca (https://www.amazon.ca/gp/product/B01KLE9KKU/ref=ppx_yo_dt_b_asin_title_o04_s00?ie=UTF8&psc=1))
Linear Rod | 8mm diameter, 500mm long | $30.89 | Amazon.ca (https://www.amazon.ca/gp/product/B07W6V35YZ/ref=ppx_yo_dt_b_asin_title_o05_s00?ie=UTF8&psc=1)

Motor Driver | 2 Pack L298N | $13.99 | Amazon.ca (https://www.amazon.ca/gp/product/B08DSFLQ3K/ref=ppx_yo_dt_b_asin_title_o05_s01?ie=UTF8&psc=1)
2x SIMAX3D Stepper Motors | NEMA 17 | $37.98 | Amazon.ca (https://www.amazon.ca/gp/product/B0857489JD/ref=ppx_yo_dt_b_asin_title_o05_s01?ie=UTF8&psc=1)
GT2 Smooth Timing Pulley | 3mm Bore | $11.99 | Amazon.ca (https://www.amazon.ca/gp/product/B086KZS9LH/ref=ppx_yo_dt_b_asin_title_o05_s03?ie=UTF8&psc=1)
Linear Rail | 300mm | $32.29 | Amazon.ca (https://www.amazon.ca/gp/product/B078M7H6GB/ref=ppx_yo_dt_b_asin_title_o05_s03?ie=UTF8&psc=1)
Microswitch | 10 Pcs | $11.99 | Amazon.ca (https://www.amazon.ca/gp/product/B08736NP44/ref=ppx_yo_dt_b_asin_title_o05_s03?ie=UTF8&psc=1)
SG90 Servos | 5 Pcs | $19.99 | Amazon.ca (https://www.amazon.ca/gp/product/B07KR24YX8/ref=ppx_yo_dt_b_asin_title_o05_s03?ie=UTF8&psc=1)
GT2 Set | Timing Belt, 4 Teeth Pulleys | $15.99 | Amazon.ca (https://www.amazon.ca/gp/product/B07PQRJL2W/ref=ppx_od_dt_b_asin_title_s03?ie=UTF8&psc=1)
Linear Bearings | 25mm Long | $20.29 | Amazon.ca (https://www.amazon.ca/gp/product/B07CRLSS7N/ref=ppx_od_dt_b_asin_title_s03?ie=UTF8&psc=1)
Linear Bearings | 45mm Long | $16.99 | Amazon.ca (https://www.amazon.ca/gp/product/B083XQTH41/ref=ppx_od_dt_b_asin_title_s03?ie=UTF8&psc=1)
Lock Nut | Assorted (M3-M12) | $15.99 | Amazon.ca (https://www.amazon.ca/gp/product/B07GNXDQJZ/ref=ppx_yo_dt_b_asin_title_o00_s00?ie=UTF8&psc=1)
Fastener Kit | Assorted (M2-M5) | $34.89 | Amazon.ca (https://www.amazon.ca/gp/product/B07GXMRYXR/ref=ppx_yo_dt_b_asin_title_o05_s00?ie=UTF8&psc=1)
Scrap MDF | 5/8” Thick | $5.00 | On Hand
Total Price | | $332.65
Table 3. Bill of Materials

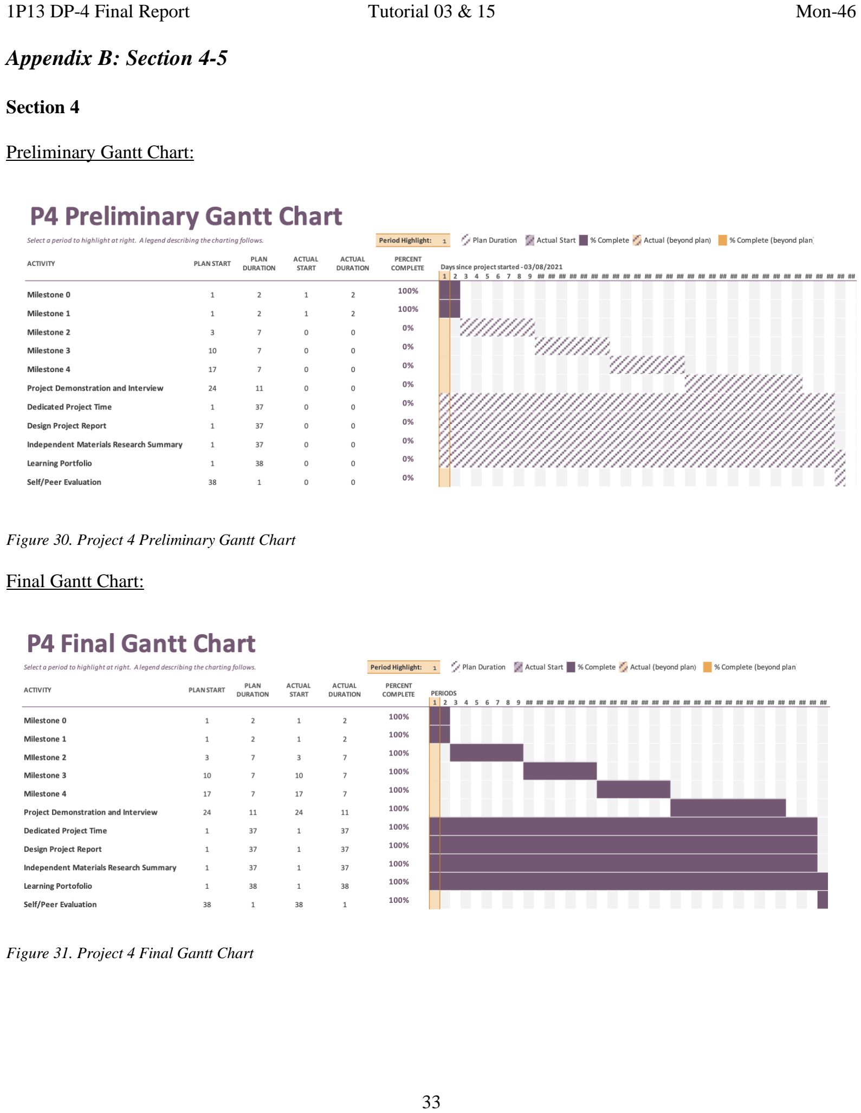
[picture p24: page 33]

Appendix B: Section 4-5

Section 4

Preliminary Gantt Chart:

Figure 30. Project 4 Preliminary Gantt Chart

Final Gantt Chart:

Figure 31. Project 4 Final Gantt Chart

Logbook of Additional Meetings and Discussions:

Friday March 5

th, 2021

❖ Attendance

- Ariel Wolle
- W. Tisuka Perera
- Milica Nenadovic

❖ Intros

❖ Organize Roles

❖ Complete Milestone 0

❖ Start Milestone 1

Monday March 8th, 2021

❖ Attendance

- Ariel Wolle
- W. Tisuka Perera
- Milica Nenadovic
- Yara Sharafeldin

❖ Intros

❖ Review and Refinement of Milestones 0 and 1

Friday March 12th, 2021

❖ Attendance

- Ariel Wolle
- W. Tisuka Perera
- Milica Nenadovic
- Yara Sharafeldin (½ hour)

❖ Type Out Client Notes

❖ Finish Researching

Monday March 15th, 2021

❖ Attendance

- Ariel Wolle
- W. Tisuka Perera

- Milica Nenadovic

❖ Technical Difficulties

❖ Finish Concept Sketches

❖ Finish Milestone 2

Friday March 19th
, 2021

❖ Attendance

- Ariel Wolle
- W. Tisuka Perera
- Milica Nenadovic
- Yara Sharafeldin

❖ Participated in Design Review #1

❖ Started Milestone 3

❖ Reflected on Design Review Notes

Monday March 22nd
, 2021

❖ Attendance

- Ariel Wolle
- W. Tisuka Perera
- Milica Nenadovic
- Yara Sharafeldin

❖ Finished up Milestone 3

Friday March 26th, 2021

❖ Attendance

- Ariel Wolle
- W. Tisuka Perera
- Milica Nenadovic
- Yara Sharafeldin

❖ Participated in Design Review #2

❖ Read through Milestone 4

❖ Reflected on Design Review Notes

Monday March 29th, 2021

❖ Attendance

- Ariel Wolle
- W. Tisuka Perera
- Milica Nenadovic
- Yara Sharafeldin

❖ Split up work

❖ Organized meeting to finish Milestone 4

Monday April 5th, 2021

❖ Attendance

- Ariel Wolle
- W. Tisuka Perera
- Milica Nenadovic

❖ Finish up CAD

❖ Start Design Report Write-up

Friday April 9

th, 2021

❖ Attendance

- Ariel Wolle
- W. Tisuka Perera
- Milica Nenadovic

❖ Prepare and Planned Video

❖ Organize Design Report

Monday April 12th, 2021

❖ Attendance

- Ariel Wolle
- W. Tisuka Perera
- Milica Nenadovic

❖ Presentation Organization

❖ Presentation

Section 5

Source Material Database:

1. H. Brorson, A. Warren, L. J. Borud, S. A. Slavin, “Lymphedema: A Comprehensive Review,” Annals of plastic surgery, Oct-2007. [Online]. Available: https://pubmed.ncbi.nlm.nih.gov/17901744/. [Accessed: 12-Apr-2021].
2. D. J. Clauw, “Fibromyalgia: an overview,” The American journal of medicine, 2009. [Online]. Available: https://pubmed.ncbi.nlm.nih.gov/19962494/. [Accessed: 12-Apr-2021].
3. E.B. Gouveia, D. Elmann, M.S. Morales, “Ankylosing spondylitis and uveitis: overview,” Rev Bras Reumatol, Oct-2012. [Online]. Available: https://pubmed.ncbi.nlm.nih.gov/23090374/. [Accessed: 12-Apr-2021].
4. D. I. Y. Machines, “Easy 3D Printable CNC Drawing Machine.” [Online]. Available: https://www.thingiverse.com/thing:4537916. [Accessed: 14-Apr-2021].
5. “AxiDraw MiniKit 2 – Compact Pen Plotter DIY-Kit,” Elektor. [Online]. Available: https://www.elektor.com/axidraw-minikit-2-compact-pen-plotter-diy-kit. [Accessed: 14-Apr-2021].

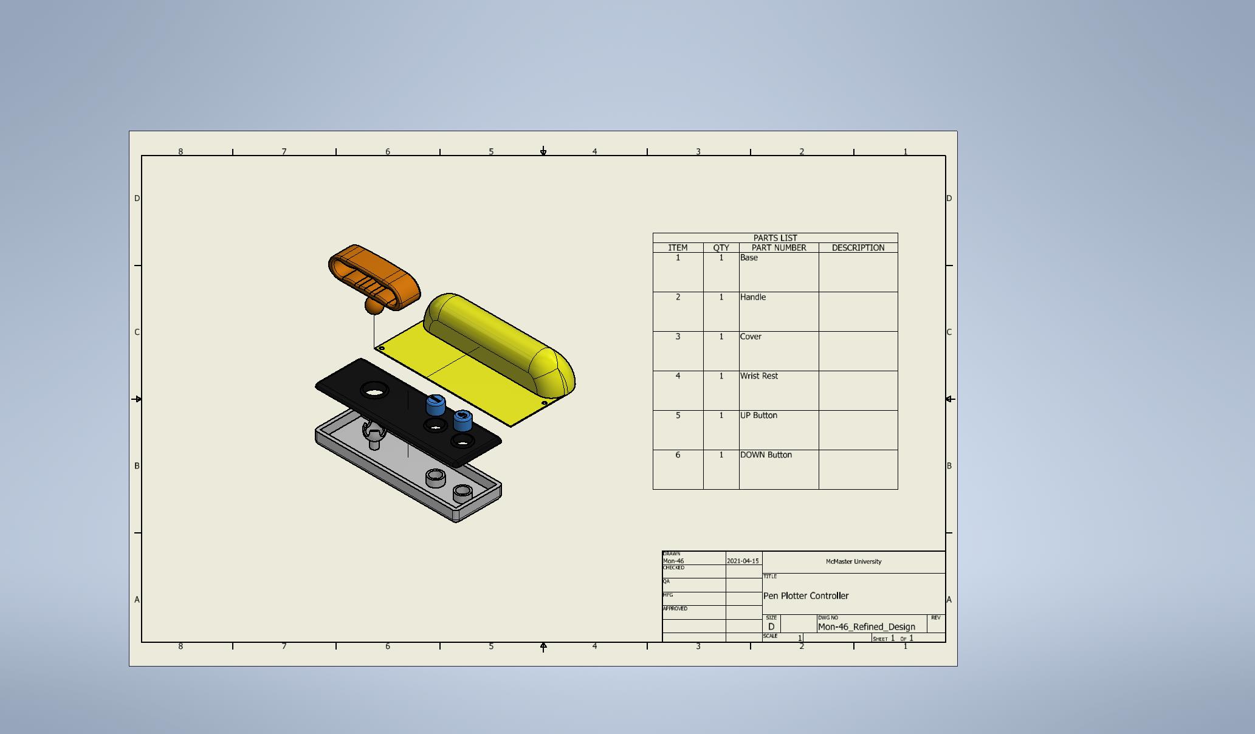
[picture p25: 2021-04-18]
Images/Mon-46_Refined_Design_exploded_view.jpg

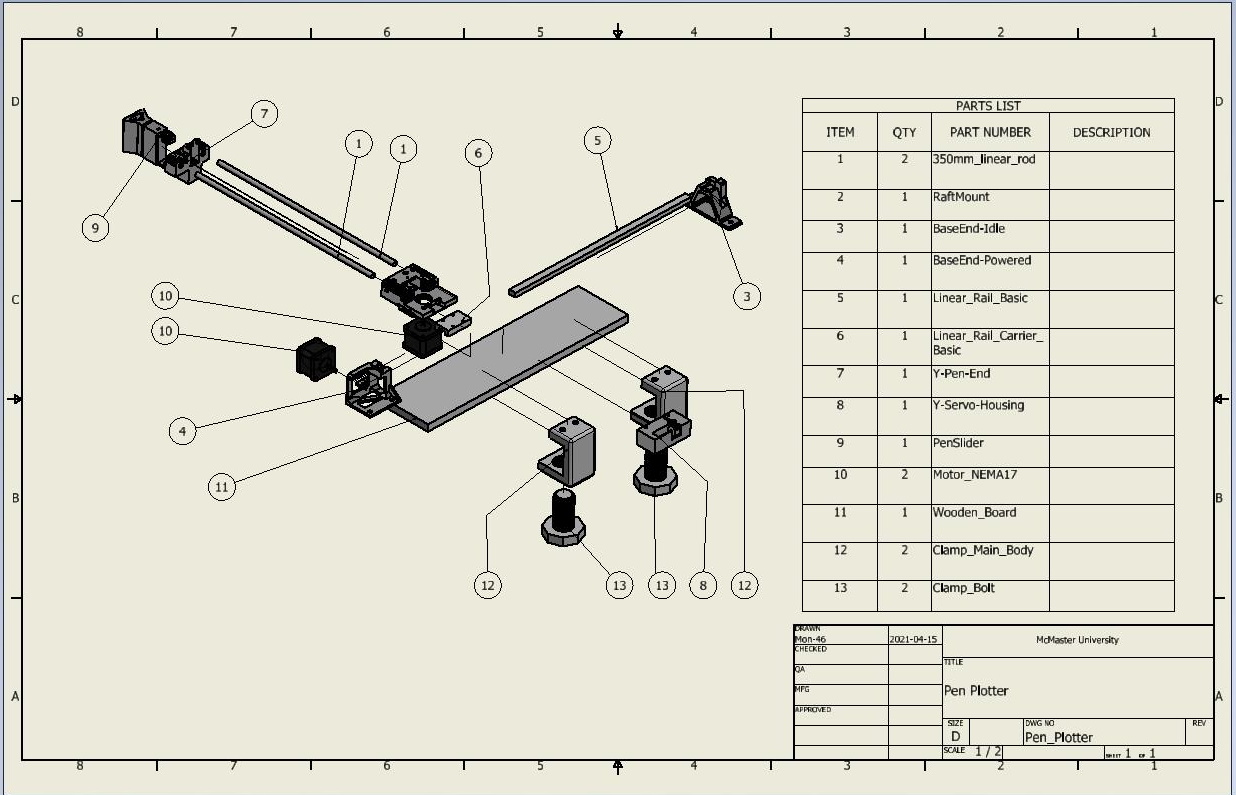
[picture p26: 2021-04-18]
Images/Pen_Plotter_exploded_view.jpg

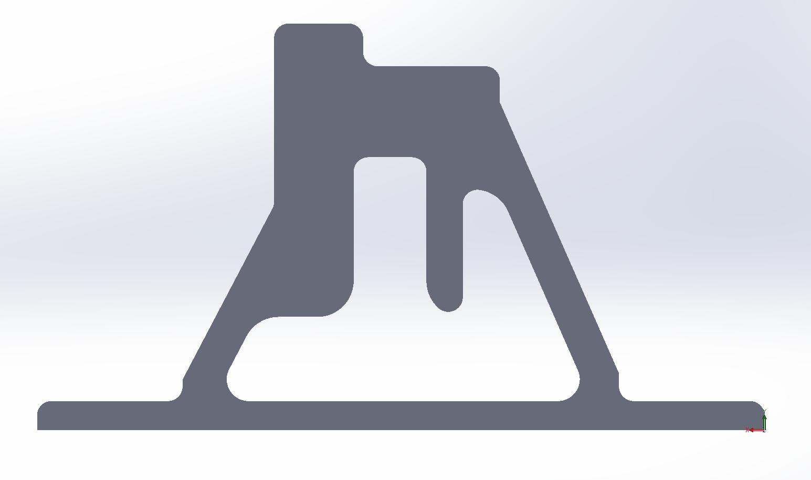
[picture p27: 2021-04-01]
CAD/Autodesk Inventor/Mon-46 Controller/Untitled.png

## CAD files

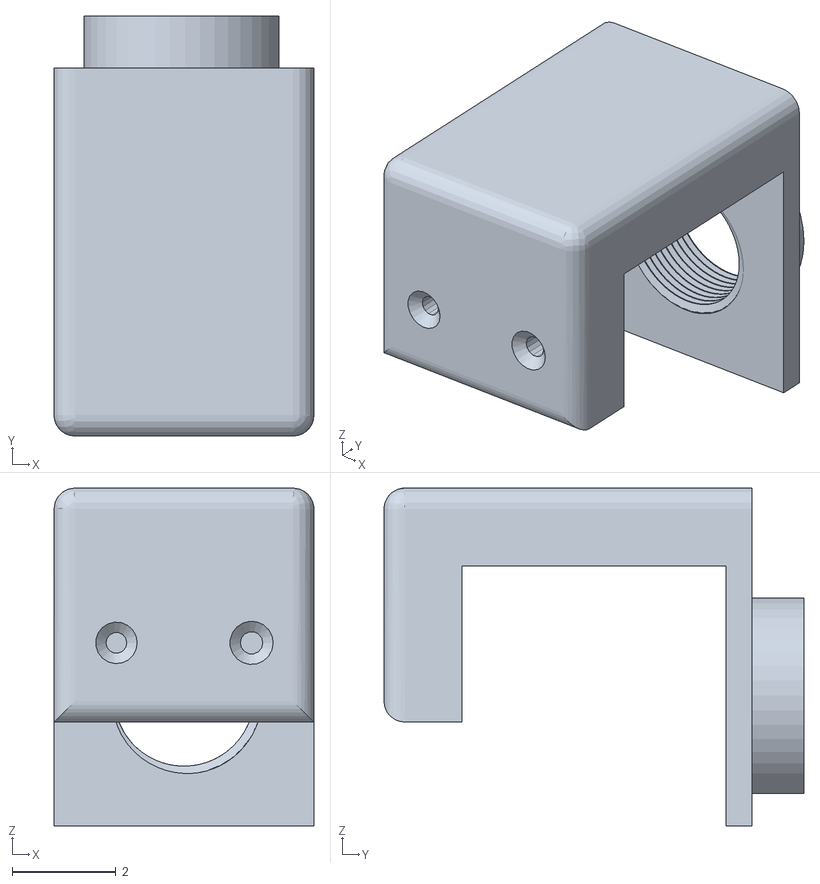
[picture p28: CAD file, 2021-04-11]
CAD/Autodesk Inventor/Clamp_Main_Body_test.stl
5.00 x 8.08 x 6.50

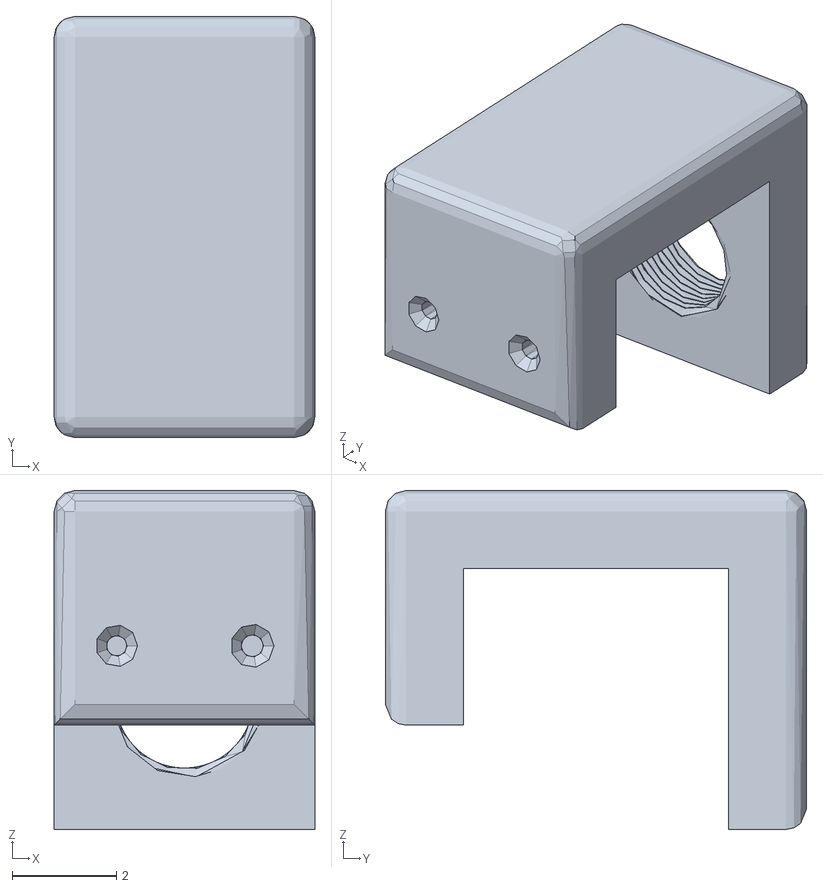
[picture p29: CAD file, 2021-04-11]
CAD/Autodesk Inventor/Clamp_Main_Body.stl
5.00 x 8.08 x 6.50

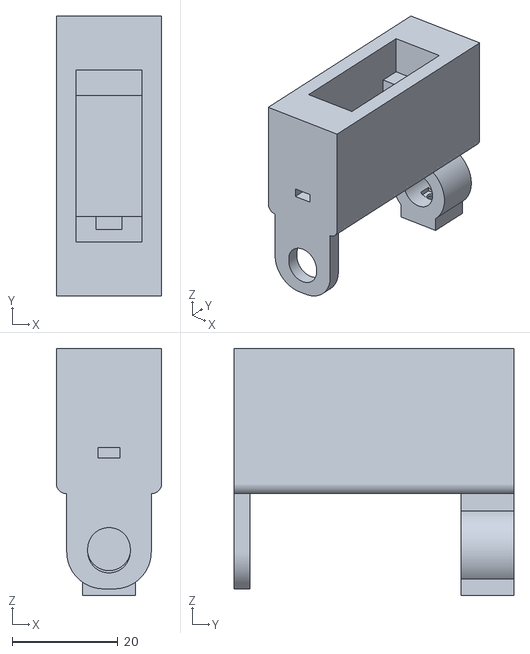
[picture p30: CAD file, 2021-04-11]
CAD/Autodesk Inventor/Imported Components/PenSlider/Static_Holder.stl
20.0 x 53.0 x 46.8

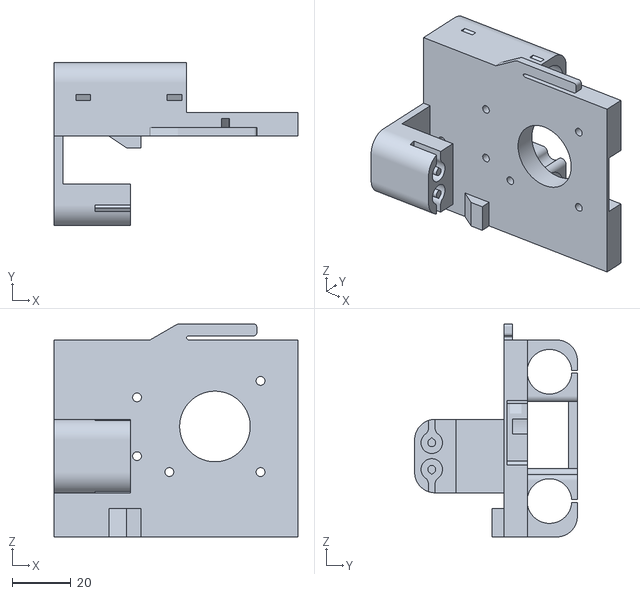
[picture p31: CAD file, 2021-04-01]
CAD/Autodesk Inventor/Mon-46 Controller/RaftMount.STL
83.0 x 55.4 x 72.4

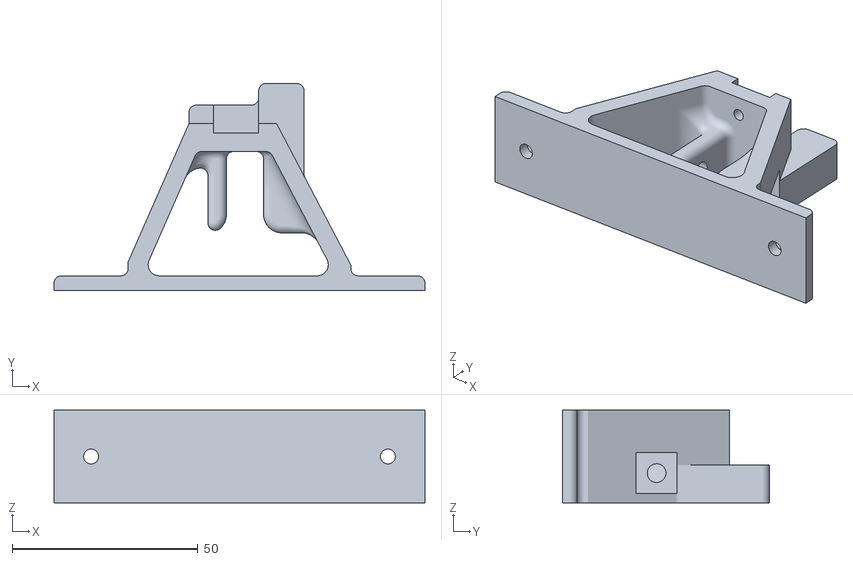
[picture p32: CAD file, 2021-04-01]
CAD/Autodesk Inventor/Mon-46 Controller/BaseEnd-Idle.STL
100.0 x 55.9 x 25.0

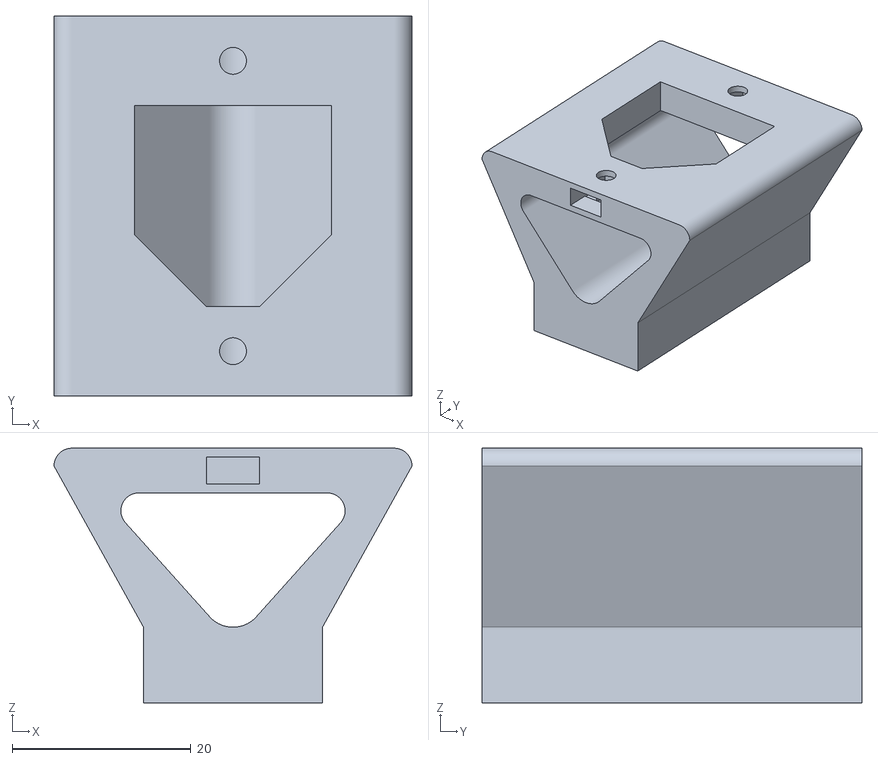
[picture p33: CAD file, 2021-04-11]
CAD/Autodesk Inventor/Imported Components/PenSlider/Rotating_Holder.stl
40.0 x 42.4 x 28.5

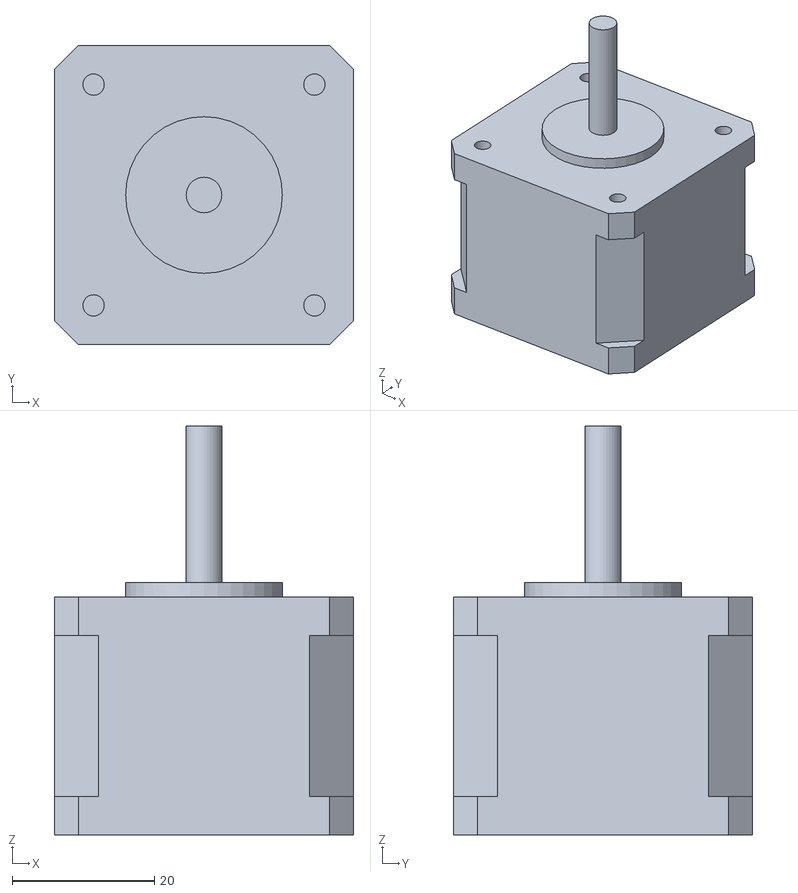
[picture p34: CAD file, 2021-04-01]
CAD/Autodesk Inventor/Mon-46 Controller/Motor_NEMA17.stl
42.0 x 42.0 x 57.4

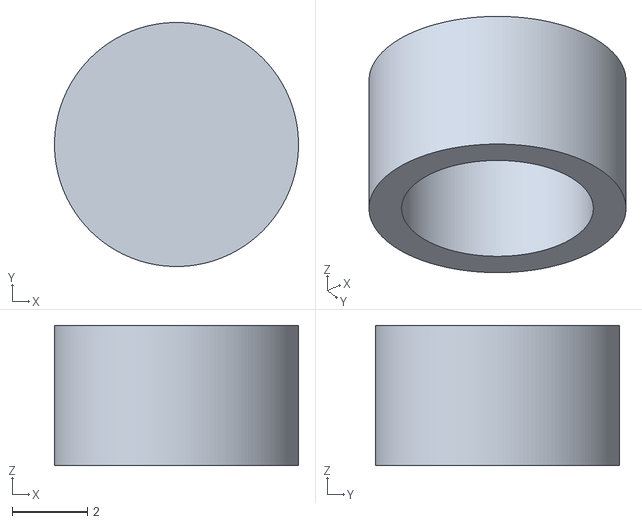
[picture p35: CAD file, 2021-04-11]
CAD/Autodesk Inventor/Imported Components/PenSlider/Rotating_Holder2.stl
6.50 x 6.50 x 3.73

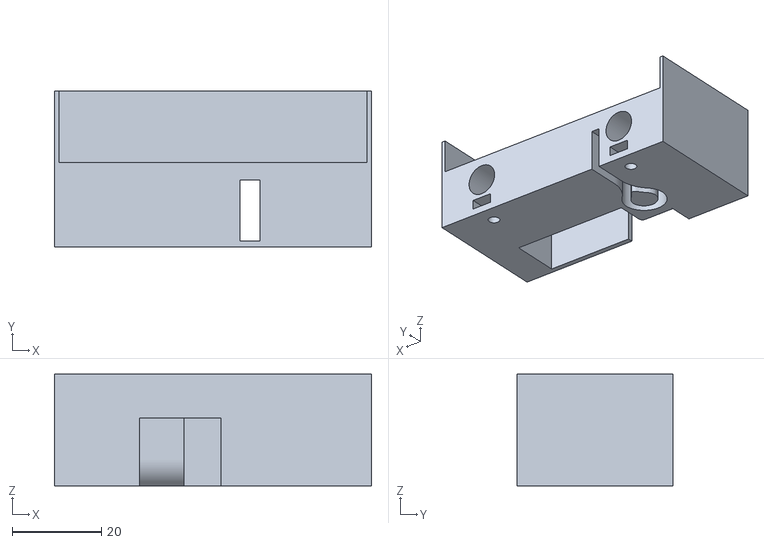
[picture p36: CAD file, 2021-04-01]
CAD/Autodesk Inventor/Mon-46 Controller/Y-Servo-Housing.STL
71.0 x 35.0 x 25.0

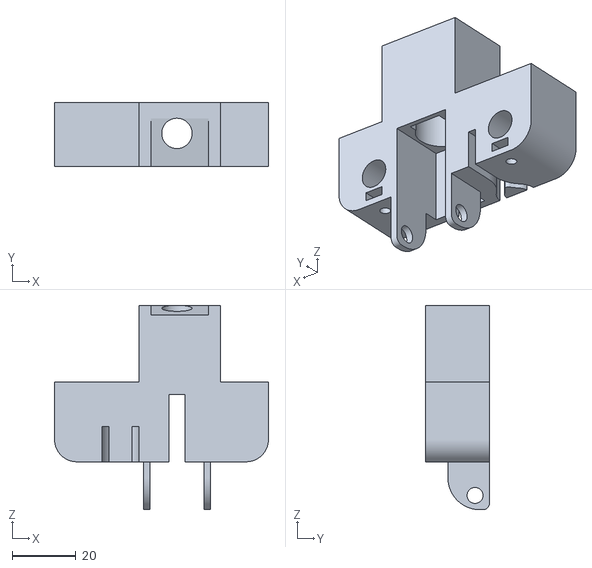
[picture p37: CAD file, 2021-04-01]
CAD/Autodesk Inventor/Mon-46 Controller/Y-Pen-End.STL
67.0 x 20.0 x 64.0

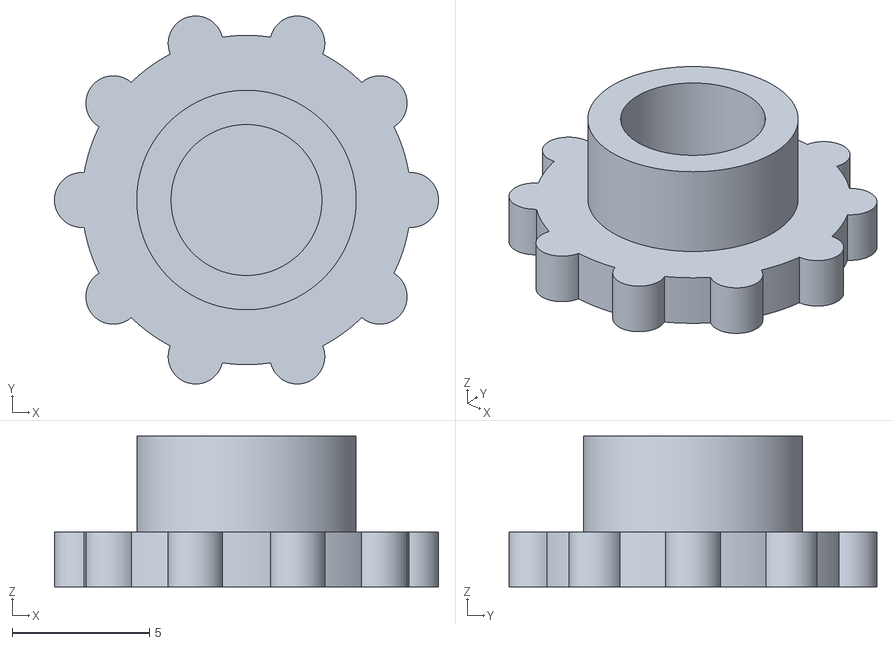
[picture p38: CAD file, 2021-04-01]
CAD/Autodesk Inventor/Mon-46 Controller/FingerDial.STL
14.0 x 13.4 x 5.50

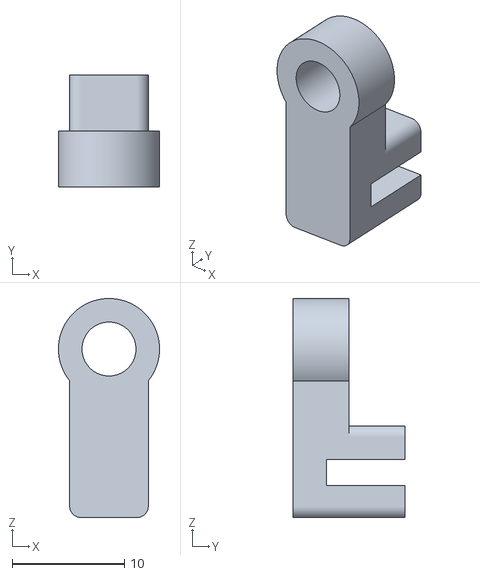
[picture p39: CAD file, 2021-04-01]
CAD/Autodesk Inventor/Mon-46 Controller/ServoArm.STL
9.00 x 10.0 x 19.5

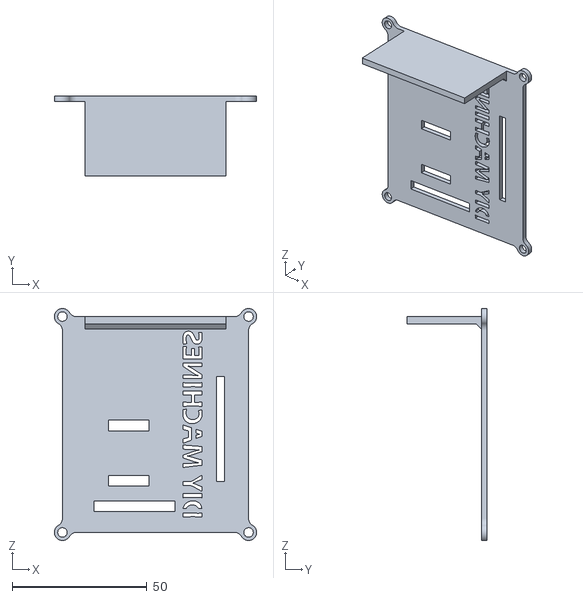
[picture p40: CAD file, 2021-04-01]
CAD/Autodesk Inventor/Mon-46 Controller/ElectronicsHousing-Lid.STL
75.0 x 29.5 x 86.0

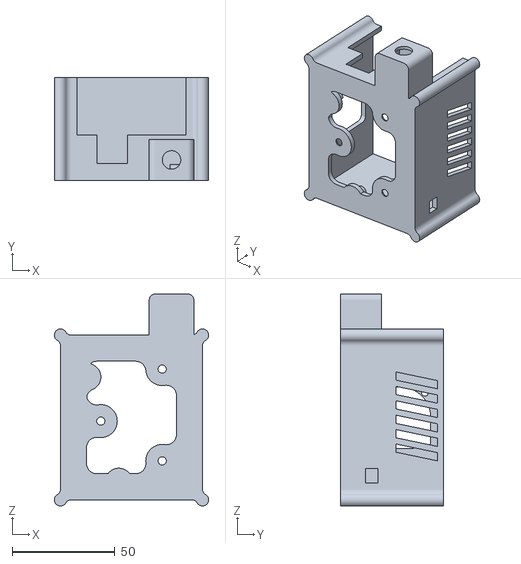
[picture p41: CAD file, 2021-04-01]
CAD/Autodesk Inventor/Mon-46 Controller/ElectronicsHousing.STL
75.0 x 50.0 x 103.0

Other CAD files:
CAD/Autodesk Inventor/Mon-46_Refined_Design (1)/Mon-46_Refined_Design/Mon-46_Refined_Design.dwg
CAD/Autodesk Inventor/Pen_Plotter.dwg
CAD/Autodesk Inventor/Imported Components/PenSlider/PenSlider.stl
CAD/Autodesk Inventor/Mon-46 Controller/BaseEnd-Powered.STL
CAD/Autodesk Inventor/350mm_linear_rod.ipt
CAD/Autodesk Inventor/55m_linear_rod.ipt
CAD/Autodesk Inventor/Clamp_Bolt.ipt
CAD/Autodesk Inventor/Clamp_Bolt.stl
CAD/Autodesk Inventor/Clamp_Main_Body.ipt
CAD/Autodesk Inventor/Device Base.ipt
CAD/Autodesk Inventor/Device Direction Button.ipt
CAD/Autodesk Inventor/Device Joystick.ipt
CAD/Autodesk Inventor/Device Rotation Button.ipt
CAD/Autodesk Inventor/Device Top Cover.ipt
CAD/Autodesk Inventor/Imported Components/BaseEnd-Powered/BaseEnd-Powered.ipt
CAD/Autodesk Inventor/Imported Components/BaseEnd-Powered/OldVersions/BaseEnd-Powered.0001.ipt
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

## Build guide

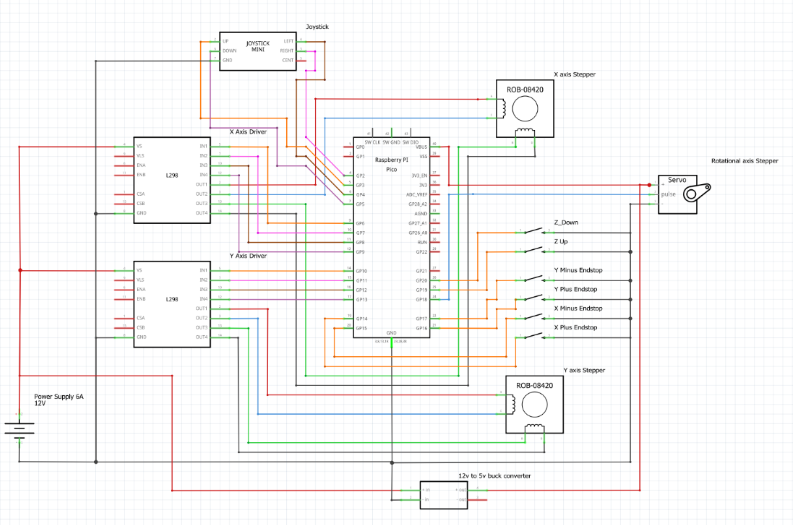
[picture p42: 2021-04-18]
Images/Wiring_diagram.png

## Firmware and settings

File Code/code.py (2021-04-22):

import board
import digitalio
import analogio
import time
import pwmio
from adafruit_motor import servo
from adafruit_motor import stepper

# Author: Ariel Wolle

# Description:
# This code is to be run on a Raspberry Pi Pico using the wiring diagram included in the wiring folder
# The main function of this code is to control a 3 axis CNC painting machine for my ENG1P13 University Course

# Input provided to the user:
# 8-axis Joystick that uses 4 microswitches as an input (GPIO2-5)
# 2 Arcade style buttons that use 2 microswitches as an input (GPOI19-20)

# Input used by the machine:
# 4 limit switches that act as endstops for the CNC machine (GPIO14-17)

# Outputs:
# 2x4 PWM GPIO for each stepper motors (GPIO6-13)
# 1 PWM GPIO for the Rotational axis servo (GPOI18)

# Setup Joystick pins
x_plus = digitalio.DigitalInOut(board.GP2)
x_minus = digitalio.DigitalInOut(board.GP4)
y_plus = digitalio.DigitalInOut(board.GP3)
y_minus = digitalio.DigitalInOut(board.GP5)

# Setup Joystick pins as input
x_plus.direction = digitalio.Direction.INPUT
x_minus.direction = digitalio.Direction.INPUT
y_plus.direction = digitalio.Direction.INPUT
y_minus.direction = digitalio.Direction.INPUT

x_plus.pull = digitalio.Pull.DOWN
x_minus.pull = digitalio.Pull.DOWN
y_plus.pull = digitalio.Pull.DOWN
y_minus.pull = digitalio.Pull.DOWN

# Setup z movement pins
z_up = digitalio.DigitalInOut(board.GP19)
z_down = digitalio.DigitalInOut(board.GP20)

# Setup z movement pins as input
z_up.direction = digitalio.Direction.INPUT
z_down.direction = digitalio.Direction.INPUT

z_up.pull = digitalio.Pull.DOWN
z_down.pull = digitalio.Pull.DOWN

# Setup stepper pwm pin
pwm_servo = pwmio.PWMOut(board.GP18, duty_cycle=2 ** 15, frequency=50)
my_servo = servo.Servo(
    pwm_servo, min_pulse=500, max_pulse=2250
)  # tune pulse for specific servo


# Setup x motor pins
x_coils = (
    pwmio.PWMOut(board.GP6, duty_cycle=2 ** 15, frequency=2000),  # A1
    pwmio.PWMOut(board.GP7, duty_cycle=2 ** 15, frequency=2000),  # A2
    pwmio.PWMOut(board.GP8, duty_cycle=2 ** 15, frequency=2000),  # B1
    pwmio.PWMOut(board.GP9, duty_cycle=2 ** 15, frequency=2000),  # B2
)
# Setup y motor pins
y_coils = (
    pwmio.PWMOut(board.GP10, duty_cycle=2 ** 15, frequency=2000),  # A1
    pwmio.PWMOut(board.GP11, duty_cycle=2 ** 15, frequency=2000),  # A2
    pwmio.PWMOut(board.GP12, duty_cycle=2 ** 15, frequency=2000),  # B1
    pwmio.PWMOut(board.GP13, duty_cycle=2 ** 15, frequency=2000),  # B2
)


# Setup x motor
x_motor = stepper.StepperMotor(
    x_coils[0], x_coils[1], x_coils[2], x_coils[3], microsteps=4
)


# Setup y motor
y_motor = stepper.StepperMotor(
    y_coils[0], y_coils[1], y_coils[2], y_coils[3], microsteps=4
)


# Setup endstop pins
x_plus_endstop = digitalio.DigitalInOut(board.GP14)
x_minus_endstop = digitalio.DigitalInOut(board.GP15)
y_plus_endstop = digitalio.DigitalInOut(board.GP16)
y_minus_endstop = digitalio.DigitalInOut(board.GP17)

# new comment

# Setup endstop pins as input
x_plus_endstop.direction = digitalio.Direction.INPUT
x_minus_endstop.direction = digitalio.Direction.INPUT
y_plus_endstop.direction = digitalio.Direction.INPUT
y_minus_endstop.direction = digitalio.Direction.INPUT

x_plus_endstop.pull = digitalio.Pull.UP
x_minus_endstop.pull = digitalio.Pull.UP
y_plus_endstop.pull = digitalio.Pull.UP
y_minus_endstop.pull = digitalio.Pull.UP

# Setup movement variables
angle = 100
my_servo.angle = 100
time.sleep(1)

# Main Loops
while True:
    time.sleep(0.001)
    # Check for x movement in joystick and that the pen plotter is not at max/min x
    if x_plus.value and (x_plus_endstop.value):
        x_motor.onestep(direction=stepper.FORWARD, style=stepper.MICROSTEP)
    elif x_minus.value and (x_minus_endstop.value):
        x_motor.onestep(direction=stepper.BACKWARD, style=stepper.MICROSTEP)

    # Check for y movement in joystick and that the pen plotter is not at max/min y
    if y_plus.value and (y_plus_endstop.value):
        y_motor.onestep(direction=stepper.FORWARD, style=stepper.MICROSTEP)
    elif y_minus.value and (y_minus_endstop.value):
        y_motor.onestep(direction=stepper.BACKWARD, style=stepper.MICROSTEP)

    # Checks that only on button is pressed for z movement
    if not (z_up.value and z_down.value):
        # Checks if z value is not at max and up button is pressed
        if z_up.value:
            if angle + 0.2 < 100:
                angle += 0.2
                my_servo.angle = int(angle)
        # Checks if z value is not at min and down button is pressed
        elif z_down.value:
            if angle - 0.2 > 0:
                angle -= 0.2
                my_servo.angle = int(angle)

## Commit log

2021-04-01 initialized more motors
2021-04-01 added adafruit motor library
2021-04-11 added wiring diagram and completed CAD model
    [Assembly1.0002.iam, Assembly1.iam, Clamp_Bolt.0004.ipt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]
2021-04-12 restructered CAD file
2021-04-12 restructured CAD folder
    [350mm_linear_rod.ipt, 55m_linear_rod.ipt, Assembly.iam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]
2021-04-18 Updated CAD
    [Assembly.0001.iam, Assembly.0001.ipn, Assembly.iam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]
